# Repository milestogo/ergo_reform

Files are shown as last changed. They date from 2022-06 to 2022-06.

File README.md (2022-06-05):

# ergo_reform
ergonomic keyboard remix for the  MNT Reform laptop

This keyboard design is for educational purposes: for me to learn through experimenting, or for for you to educate me. Little remains of MNT's tested design. I have not tested the current version.  Hardware may have dangerous, ignorant or time wasting mistakes. Software is not guaranteed to run or be useful for any purpose. 

## Images
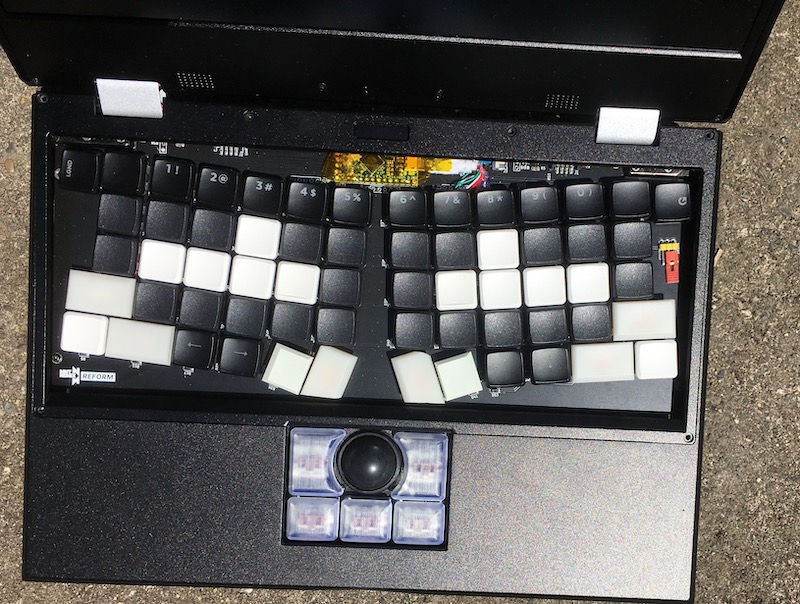
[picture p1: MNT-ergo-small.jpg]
Ergo keyboard V1


## Changes from MNT reform

* Ergonomic key layout.
* Removed backlight
* Added optional Kailh sockets for switches without RGB backlight. These sockets are cheaper than switches, so I like them in protototypes. While there is room for the sockets above the motherboard, it's only a couple thicknesses of paper. This probably reduces cooling and may permit chort circuits. 
* Removed surface mount Atmega32u4 (cost and chip shortages). Instead it uses the 3 volt Adafruit itsy bitsy. https://learn.adafruit.com/introducting-itsy-bitsy-32u4/pinouts you must hack a USB cable to connect the MCU to the keyboard (see screenprint for "airwire"). You MUST modify the itsyBitsy to disable or remove the 3v3 regulator. Failure to do so may damage the motherboard. 
* Optional power off switch/jumper that can completly remove power to the keyboard.
* Lots of break out pins, so that it should be possible to use the PCB with other MCUs.
* Desktop option for through hole OLED modules. Available from online retailers
* Added partial RGB backlighting. Keys ESC,~,1,2, F, Thumb keys, J, 9,0,-,= have backlights. This is enough to show battery voltage or where to put your hand in the dark. There are jumpers to bypass the top row LEDs, or add separate LED strips. This uses SK Mini-E rgb lights. 

## errata / changelog / todo
* V0 - the pictured version - had the power disconnect on the 5 volt side instead of 3v. ooops. 

# License
This work is derived from work Copyright 2018-2020 MNT Research GmbH.
Modifications Copyright 2022 milestogo are released under the license matching the MNT reform original file or the attached MIT license where not othewise specified.  

The following licenses are used in the project, unless specified differently in a particular subfolder:

- Schematics, PCBs: [CERN-OHL-S v2](https://www.ohwr.org/project/cernohl/wikis/uploads/002d0b7d5066e6b3829168730237bddb/cern_ohl_s_v2.txt)
- Other documentation, artwork, photos and drawings that are not trademarks (see below): [CC-BY-SA 4.0](https://creativecommons.org/licenses/by-sa/4.0/legalcode)
- Software, firmware: Various. [GPL 3.0](https://www.gnu.org/licenses/gpl-3.0.en.html) if not specified otherwise in the file/subdirectory.

The "MNT" and "MNT REFORM" logos are trademarks of MNT Research GmbH. 

## MIT license
Permission is hereby granted, free of charge, to any person obtaining a copy of this software and associated documentation files (the “Software”), to deal in the Software without restriction, including without limitation the rights to use, copy, modify, merge, publish, distribute, sublicense, and/or sell copies of the Software, and to permit persons to whom the Software is furnished to do so, subject to the following conditions:

The above copyright notice and this permission notice shall be included in all copies or substantial portions of the Software.

THE SOFTWARE IS PROVIDED “AS IS”, WITHOUT WARRANTY OF ANY KIND, EXPRESS OR IMPLIED, INCLUDING BUT NOT LIMITED TO THE WARRANTIES OF MERCHANTABILITY, FITNESS FOR A PARTICULAR PURPOSE AND NONINFRINGEMENT. IN NO EVENT SHALL THE AUTHORS OR COPYRIGHT HOLDERS BE LIABLE FOR ANY CLAIM, DAMAGES OR OTHER LIABILITY, WHETHER IN AN ACTION OF CONTRACT, TORT OR OTHERWISE, ARISING FROM, OUT OF OR IN CONNECTION WITH THE SOFTWARE OR THE USE OR OTHER DEALINGS IN THE SOFTWARE.

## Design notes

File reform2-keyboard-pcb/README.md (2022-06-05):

# keyboard remix by milestogo

This keyboard design is for educational purposes: for me to learn through experimenting, or for for you to educate me. 
Little remains of MNT's tested design. I have not tested. It may have dangerous or time-wasting errors. 

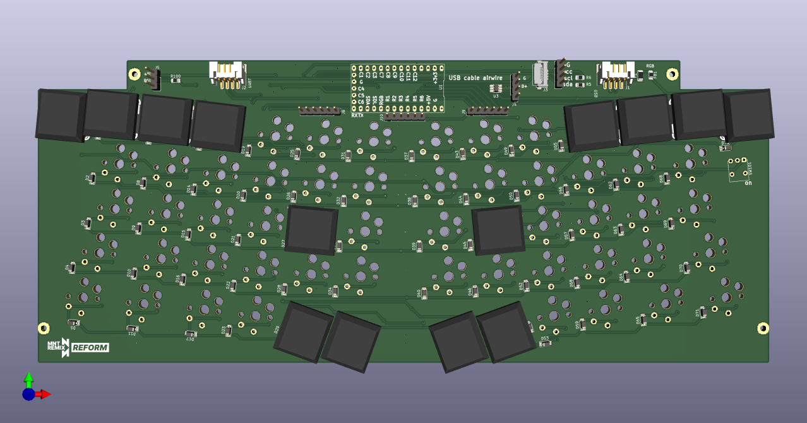
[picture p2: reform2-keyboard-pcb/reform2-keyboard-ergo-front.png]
Front of PCB image Front of PCB


Warning!
this PCB is designed to use an adafruit itsy bitsy 3v3 model. You MUST disable the 3v regulator if you want to avoid doing bad things to your mnt reform laptop. Remove R9 above the voltage regulator at a minimum. Remove voltage regulator to be sure. 
Remember to flash the MCU before removing the regulator. Place a current limiting resistor at J14, marked "EN" to temporarily enable the regulator. 

Changes from MNT reform
- Ergonomic key layout. 
- Removed backlight
- Added partial RGB backlighting. Keys ESC,~,1,2, F, Thumb keys, J, 9,0,-,= have backlights. This is enough to show battery voltage or where to put your hand in the dark. There are jumpers to bypass the top row LEDs, or add separate LED strips. This uses SK Mini-E rgb lights. Since they are bottom mount and optional, the power caps for them are also bottom & optional. 
- Added optional Kailh sockets for switches without RGB backlight. These sockets are cheaper than switches, so I like them in protototypes. These reduce thermal and short protection. 
- Removed surface mount Atmega32u4 and related voltage chips (cost and chip shortages). Instead it uses the 3 volt Adafruit itsy bitsy. https://learn.adafruit.com/introducting-itsy-bitsy-32u4/pinouts
--you must hack a USB cable to connect the MCU  to the keyboard (see silkscreen for "USB airwire"). 
- Optional power off switch/jumper that can completely remove 3v3 power to the keyboard.
- Lots of break out pins, so that it should be possible to use the PCB with other MCUs.  
- Desktop option for through hole OLED modules. Available from online retailers

These changes are made available under the MIT License: 
Copyright © 2022 milestogo

Permission is hereby granted, free of charge, to any person obtaining a copy of this software and associated documentation files (the “Software”), to deal in the Software without restriction, including without limitation the rights to use, copy, modify, merge, publish, distribute, sublicense, and/or sell copies of the Software, and to permit persons to whom the Software is furnished to do so, subject to the following conditions:

The above copyright notice and this permission notice shall be included in all copies or substantial portions of the Software.

THE SOFTWARE IS PROVIDED “AS IS”, WITHOUT WARRANTY OF ANY KIND, EXPRESS OR IMPLIED, INCLUDING BUT NOT LIMITED TO THE WARRANTIES OF MERCHANTABILITY, FITNESS FOR A PARTICULAR PURPOSE AND NONINFRINGEMENT. IN NO EVENT SHALL THE AUTHORS OR COPYRIGHT HOLDERS BE LIABLE FOR ANY CLAIM, DAMAGES OR OTHER LIABILITY, WHETHER IN AN ACTION OF CONTRACT, TORT OR OTHERWISE, ARISING FROM, OUT OF OR IN CONNECTION WITH THE SOFTWARE OR THE USE OR OTHER DEALINGS IN THE SOFTWARE.

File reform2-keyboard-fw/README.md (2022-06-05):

# MNT Reform 2.0 Keyboard Firmware

## Code Structure

- `constants.h`: Define which keyboard variant you want to build for
- `keyboard.c`: Main entrypoint that includes the chosen matrix file (keyboard layout)
- `matrix.h`: Keyboard layout definition (default)
- `matrix_*.h`: Alternative layouts
- `backlight.c`: Keyboard backlight control
- `menu.c`: OLED Menu handling
- `oled.c`: OLED graphics control
- `remote.c`: Communication with MNT Reform motherboard LPC
- `hid_report.c`: USB HID raw report handler (commands sent by OS)
- `powersave.c`: Low power/sleep mode
- `descriptors.c`: USB HID descriptors
- `i2c.c`: Soft I2C master implementation (for OLED)
- `serial.c`: Soft UART implementation
- `font.c`: Bitmap data for OLED font and icons

## Dependencies

### Debian/Ubuntu

`apt install gcc-avr avr-libc dfu-programmer`

### Mac

*TODO: is this correct?*

```
brew tap osx-cross/avr
brew install avr-gcc
brew install dfu-programmer
```

## Hacking

To change the keyboard layout, adjust the `matrix` arrays in `keyboard.c`.

## Building

*Important*: Adjust the variant settings in `constants.h` do match your keyboard or laptop model.
I.e., if you are targeting the Standalone Keyboard, uncomment the `#define KBD_VARIANT_STANDALONE`.

To build, type:
`make`

To flash, put your keyboard into [flashing mode](https://mntre.com/reform2/handbook/parts.html#keyboard-firmware) and run:
`sudo ./flash.sh`

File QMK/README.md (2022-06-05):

#Incomplete work

This firwmare does not yet work in the mnt reform.
The keymap and OLED graphics should work. 
The serial connection has not been tested. 
The problem is that QMK expects USB power at boot. Looking at similar examples in keyboards/bioi/main.c , we probably need to create a custom main.c
The order would be 
1) init everything. 
2) open serial, find the LPC. 
3) Wait for power on, talk to LPC, exit power saving. 
4) Wait for USB VBUS
5) Start USB, 
6) standard QMK boot cycle. 

To use, copy or symlink this directory into the $QMK/keyboards/ directory

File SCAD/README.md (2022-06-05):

# Lorize: a family of low profile 60% ergonomic keyboards that aren't too weird.  

These should be familiar to users of a MS natural or Sculpt keyboard, but pull in elements from the boardrun, alice, and kinesis keyboards. 
Available in desktop and MNT reform versions.

The lorize.scad file is intended to be used with the openscad configurator. You can change the type of keyboard (desktop, laptop, mutants), and the layer. The output can be used for laser cutting plate and case files. The POS files are used as an easy way to export centroid information from kicad & import into SCAD, which is used to make the bottom layer cutouts. 

lorize3 folder is for a desktop version of the PCB. it can be split for tenting, or used unsplit. This PCB can be soldered using only through hole 
techniques (no stencil).

The PCB for the laptop version is located at github milestogo/reform,in the ergo1 branch. This was done as a remix of the original keyboard, so that the factory firmware will still work. The board was updated to be single sided to reduce cost/effort of assembly. There isn't quite enough room to fit on top to fit a pro micro, so it requires SMD work. 

#Todos.
the latest ergo reform PCB thumb positions are a few mm away from the scad positions. Update.

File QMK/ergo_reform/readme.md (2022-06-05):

# ergo_reform

ergo_reform

*A short description of the keyboard/project*

* Keyboard Maintainer: [milestogo](https://github.com/milestogo)
* Hardware Supported: *The PCBs, controllers supported*
* Hardware Availability: *Links to where you can find this hardware*

Make example for this keyboard (after setting up your build environment):

    make ergo_reform:default

Flashing example for this keyboard:

    make ergo_reform:default:flash

See the [build environment setup](https://docs.qmk.fm/#/getting_started_build_tools) and the [make instructions](https://docs.qmk.fm/#/getting_started_make_guide) for more information. Brand new to QMK? Start with our [Complete Newbs Guide](https://docs.qmk.fm/#/newbs).

## Bootloader

Enter the bootloader in 3 ways:

* **Bootmagic reset**: Hold down the key at (0,0) in the matrix (usually the top left key or Escape) and plug in the keyboard
* **Physical reset button**: Briefly press the button on the back of the PCB - some may have pads you must short instead
* **Keycode in layout**: Press the key mapped to `RESET` if it is available

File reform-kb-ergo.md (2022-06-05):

## Design goals & trade-offs:

# Make it hurt less
Remove as many of the un-ergonomic factors as possible, while remaining within the footprint of the Reform keyboard.

# Optimize for portable use on the lap.
People will put their laptops at different heights and rotations. Most of these won't be ergonomic. We'll try to avoid anything that makes it worse.

While we can increase the hand to hand spacing up to almost 4cm, this moves the palm resting position out to the side enough that it unbalances a laptop when only one hand is used. Instead we're increasing the angle & keeping the hands relatively close. This normally requires an increase in tenting angle, which we're appoximating by changing the pinky location. 

Most designs here separate the D ahd K middle fingers by ~106mm. Most ergo keyboards are 2-3 cm further apart, but tip the laptop.  From a trawl through anthropometric data, people with forearms of average North American size should have a ~18 degree angle, but we're limited to  ~14 degrees in order to stay within the limits of the reform keyboard Y depth. Too flat is probably less bad than too angled given the range of positions a laptop will be placed in. 

best angle = atan((shoulders width -d_to_k_key_spacing)/( 2 * armlen));

#Minimize learning curve
  * Removing the number row is a big step for most people.  Providing a comfortable 10key layer will help some people, this is down to the key map. 
  * Removing the Fkeys is bad for some, but is easier to solve with a FN key/keymap. 
  * Use big keys where people are used to big keys. Most designs use 1.5U keys for shift & GUI, to accomodate current muscle memory.  
  
# Avoid custom keycaps
* We want to only use 1u and 1.5u keycaps. In practice, the top right and top left key may need to be shaved down to clear the MNNT bezel. The thumb buttons would benefit from a more diagonal shape. 

# Reduce ulnar flexion/deviation
Ulnar flexion occurs when the fingers are not in line with the bones of the forearm, so that there is a <180 degree angle between little finger and the outside of the arm). 

Ulnar flexion is the norm on laptop keyboards, where the hands are too close together and the keyboard is entirely parallel to the chest.

To fix this, we want the front to back line of keys to be  parallel to the bones of the forearm. This is changes depending on how far apart the hands are (x axis) as this changes the angle between the forearms and the chest.  Reducing pronation of the hands (thumbs to ceiling) allows the fingers to move together. Staggering keys so that the little finger is further away and the index finger is closer has the effect of rotating the center of the palm around the z-axis, reducing ulnar flexion. This technique has a limited range, beause people have different size fingers. 

Because of the limited depth of the reform keyboard, we can't use much finger stagger, but we've added some.  

# Minimize Radial Deviation
Radial flexion is caused by roating the hand inwards, as in rotating the palm to allow the little finger to hit the backspace key,  or to hit a key inwards of the index finger.  Laptop keyboards start with so much ulnar deviation, radial movement usually isn't a problem. Some variations here (smallreform_thumbs) add a column of keys between the index fingers. The lower positions are not good for radial deviation when activated by the fingers, and create ulnar deviation when activated by the thumb. Save them for unused keys.

#Reduce pronation of the hand
Pronation is palms forced parallel to the floor, when they would be more comfortable with the thumbs pointing upwards.

We gain a litle bit here by straightening the ulnar deviation, but proper tenting would require changing the top face of the laptop.

# Move work from the little finger to the Thumbs.
 This helps avoid "emacs-pinky", and somewhat reduces the need to pronate the hand in chorded combinations. Frequently used keys like Backspace, GUI, CTL and Enter should be moved to thumb keys.

 Some people have flexible or long thumbs that allow them to hit keys underneath the index fingers. Most people use excessive wrist flexion to force it.  

 There are two thumb keys on each hand in all designs. In the smallreform_thumbs version has 5 in total, with slightly worse ergonomics. While the bottom index finger key could be used for an inner thumb key, but I suspect it is bad for most people. 

# Avoid Wrist extension
Where the tip of the fingers are above the line from elbow to wrist. Laptops create a problem when the user is pressing down on the palms to keep the laptop steady.  Possibly some thin (~3-5mm), cork or rubber  wrist wrests could help wrist extension & contribute a degree or two of tenting?

# Think about palmar flexion
Where the tip of the fingers are below the line from the elbow to the wrists. Also known as the T-rex or bunny position. This can be a problem for tall laptops on tables, where there isn't a good line from the elbows to the keys. Ideally we'd move the laptop to the lap or use a separate keyboard.

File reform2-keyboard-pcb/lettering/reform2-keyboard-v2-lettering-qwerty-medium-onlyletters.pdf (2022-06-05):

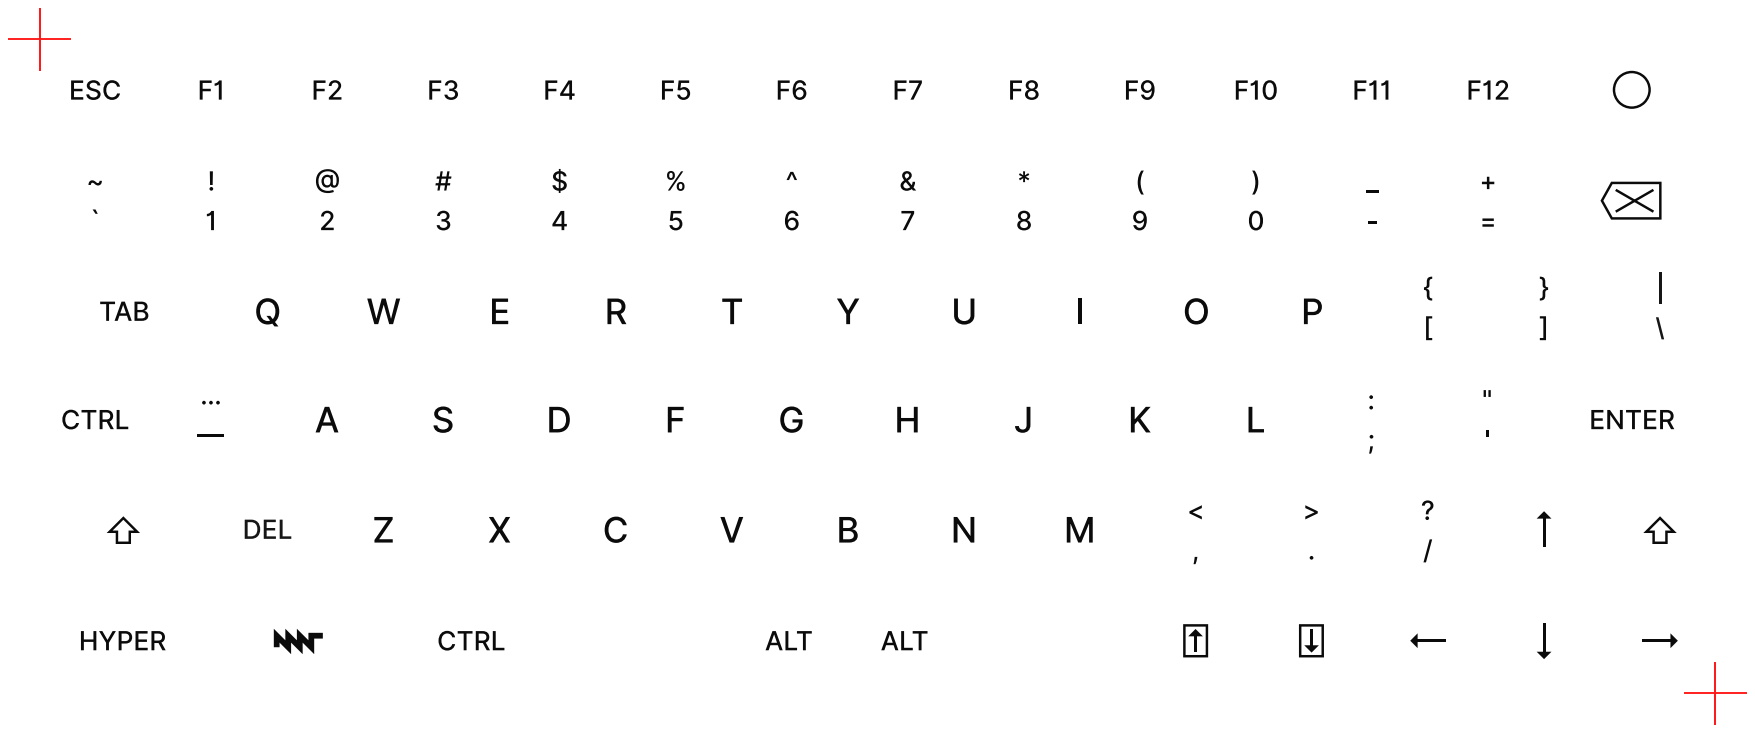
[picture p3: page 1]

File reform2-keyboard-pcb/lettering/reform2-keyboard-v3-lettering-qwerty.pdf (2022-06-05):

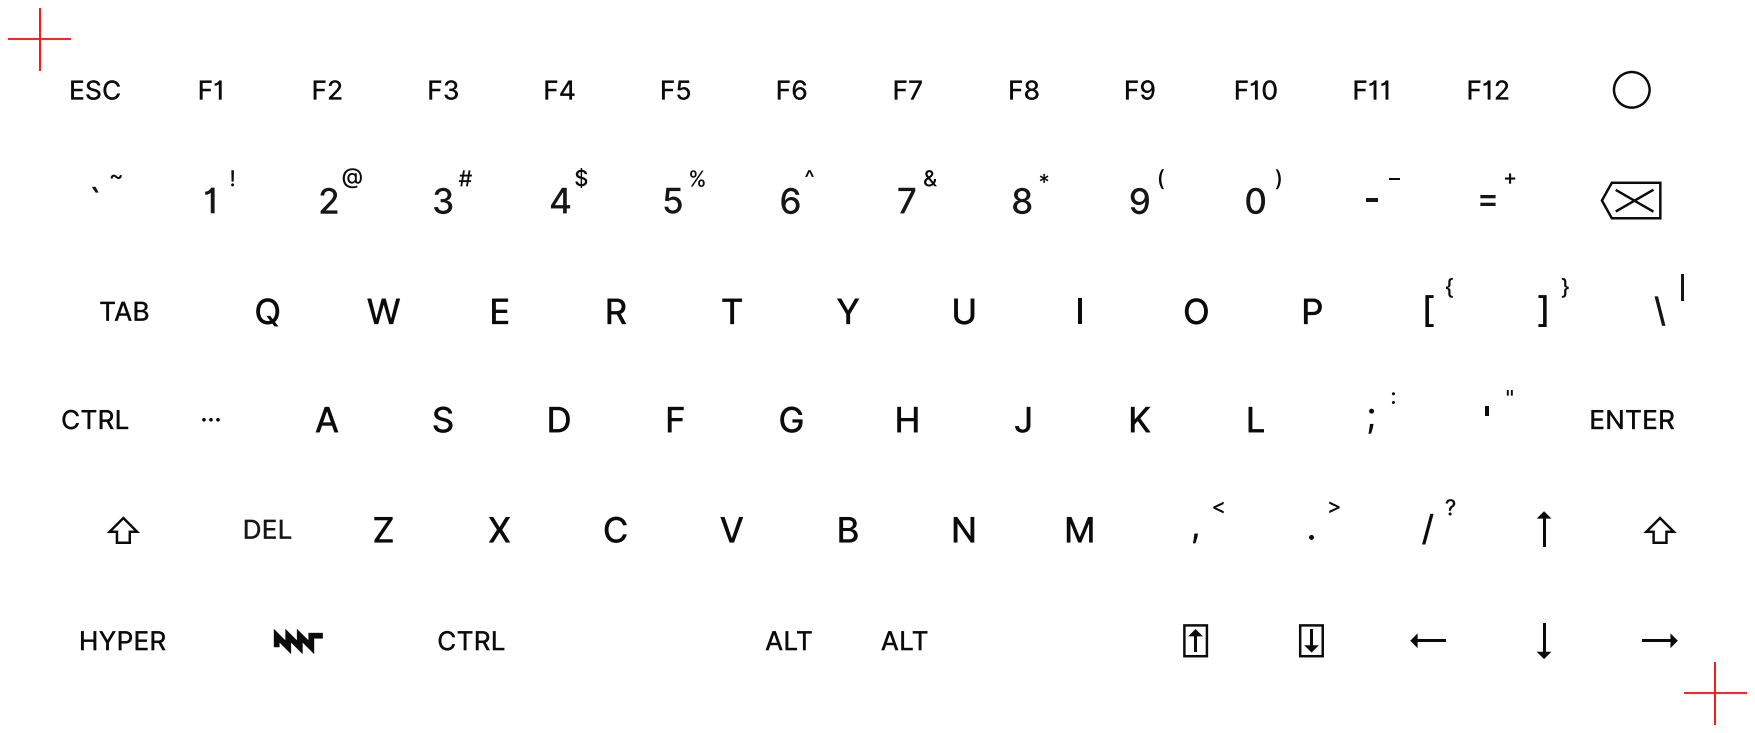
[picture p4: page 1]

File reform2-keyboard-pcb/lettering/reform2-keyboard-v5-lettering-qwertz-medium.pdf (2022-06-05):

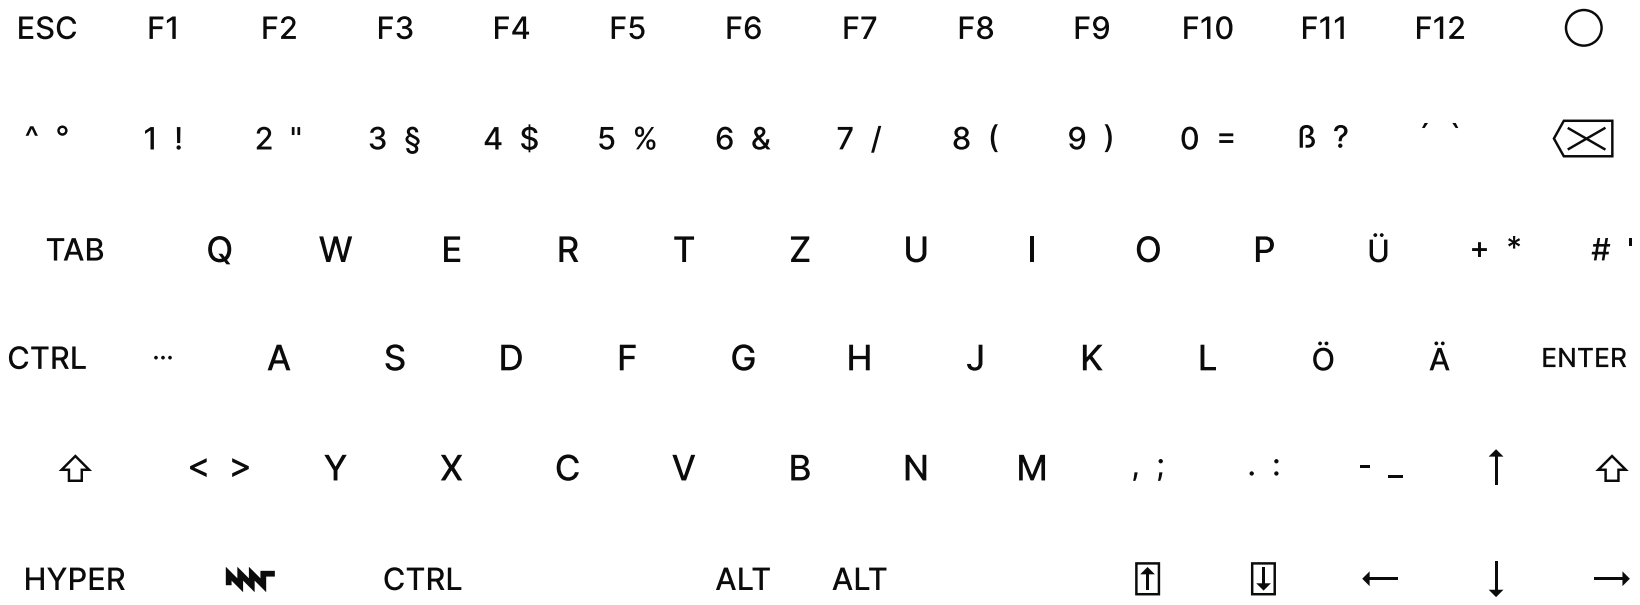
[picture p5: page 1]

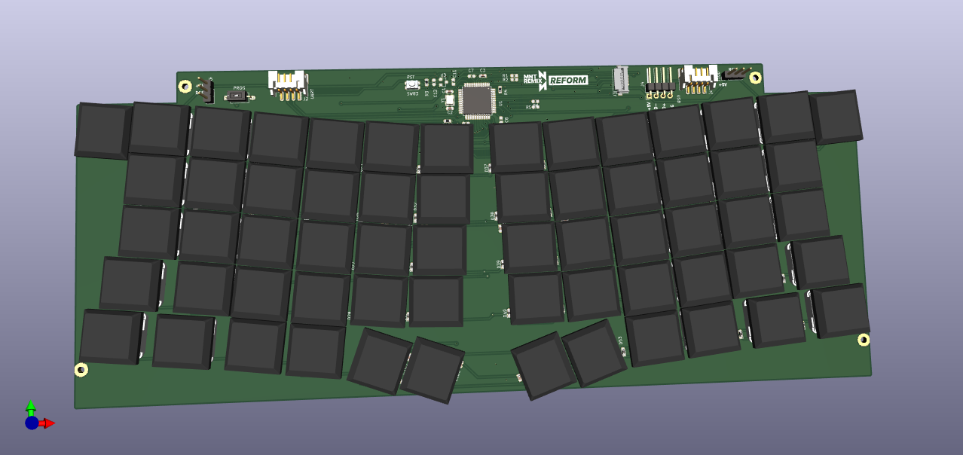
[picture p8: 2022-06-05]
reform2-keyboard-pcb/reform2-keyboard-ergo.png

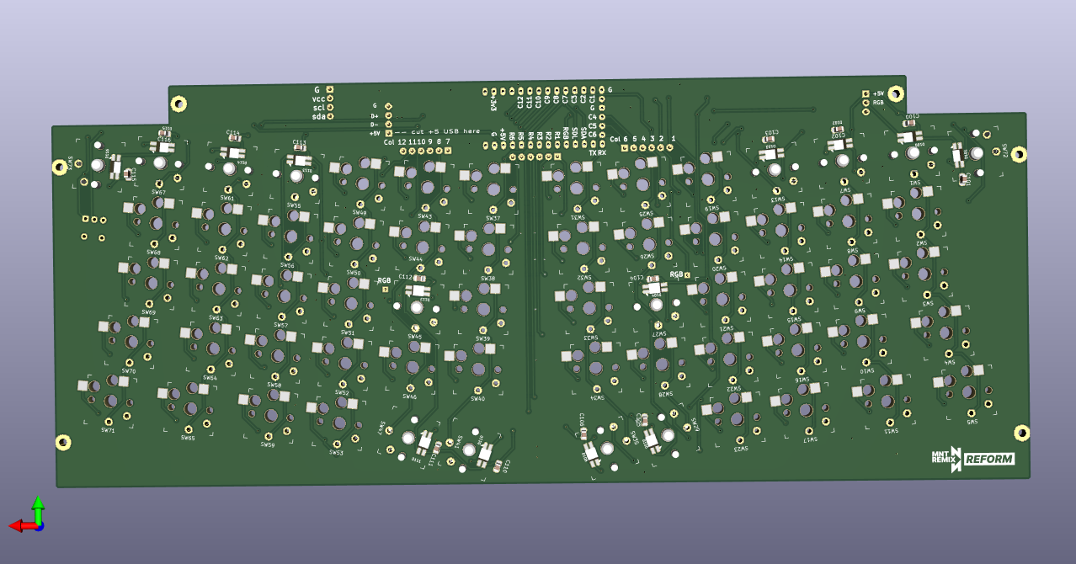
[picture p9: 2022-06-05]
reform2-keyboard-pcb/reform2-keyboard-ergo-back.png

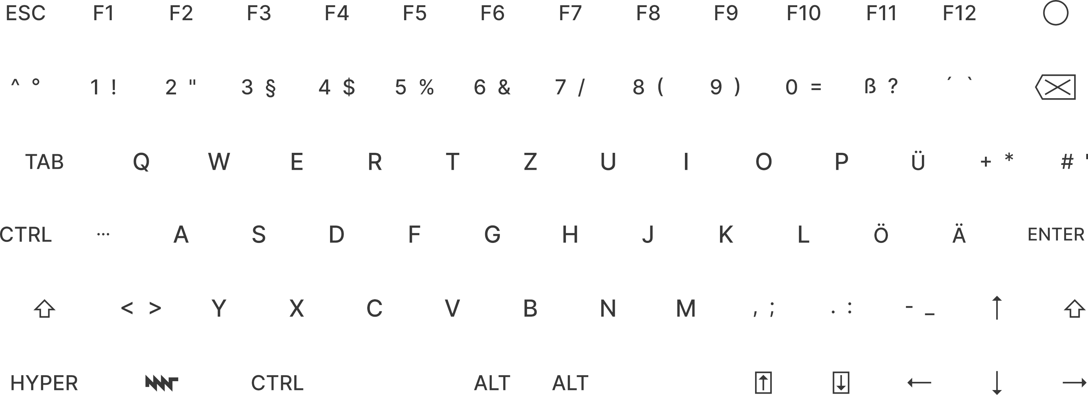
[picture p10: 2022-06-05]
reform2-keyboard-pcb/lettering/reform2-keyboard-v5-lettering-qwertz-medium.png

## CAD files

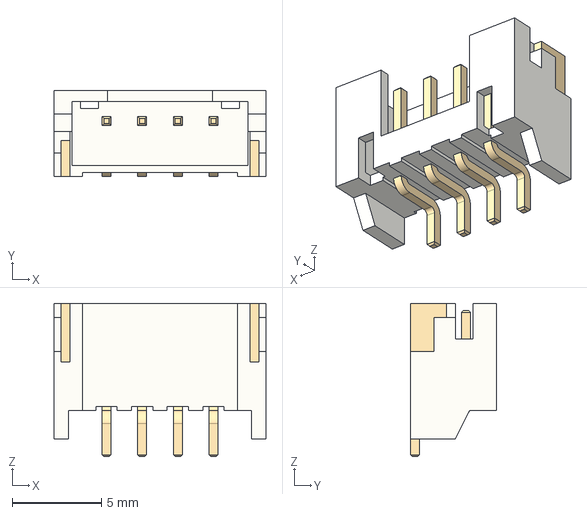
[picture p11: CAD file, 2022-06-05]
reform2-keyboard-pcb/3d-models/S4B-PH-SM4-TB.stp
11.9 x 4.80 x 8.60 mm

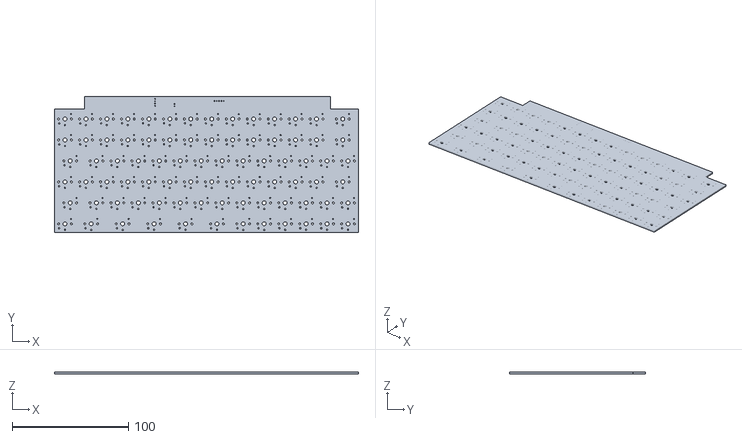
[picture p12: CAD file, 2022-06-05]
reform2-keyboard-pcb/reform2-kbdtest.stl
261.0 x 116.8 x 1.60

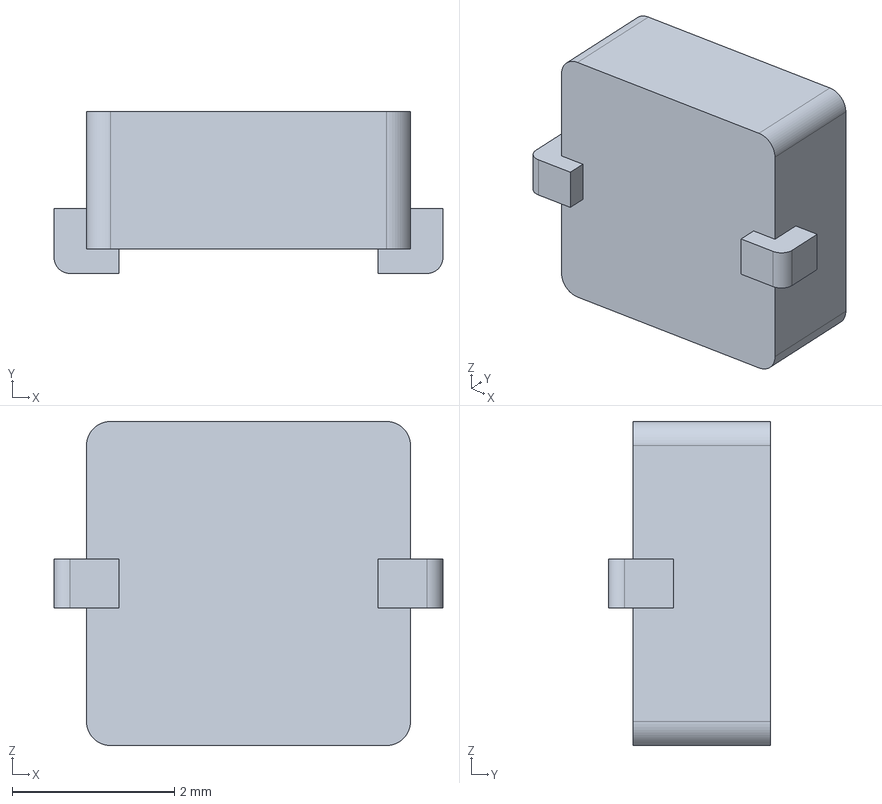
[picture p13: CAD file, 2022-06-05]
reform2-keyboard-pcb/3d-models/srp4020.stp
4.80 x 2.00 x 4.00 mm

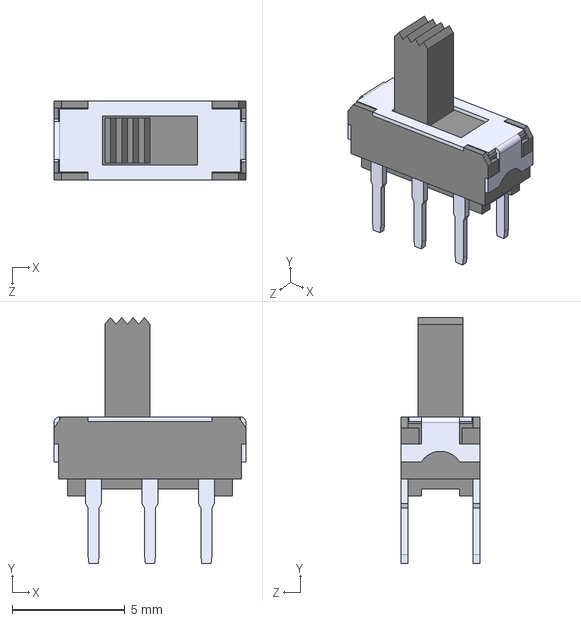
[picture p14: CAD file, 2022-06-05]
reform2-keyboard-pcb/3d-models/EG1271A.step
8.50 x 10.9 x 3.50 mm

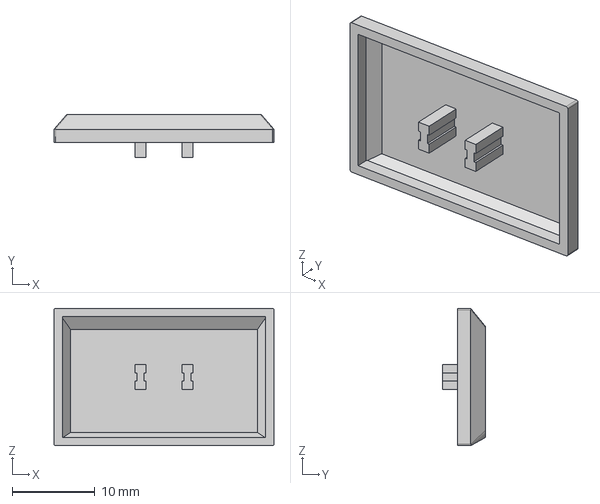
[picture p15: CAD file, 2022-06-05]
reform2-keyboard-pcb/3d-models/Kailh - keycap 1.5 v2.step
26.6 x 5.23 x 16.6 mm

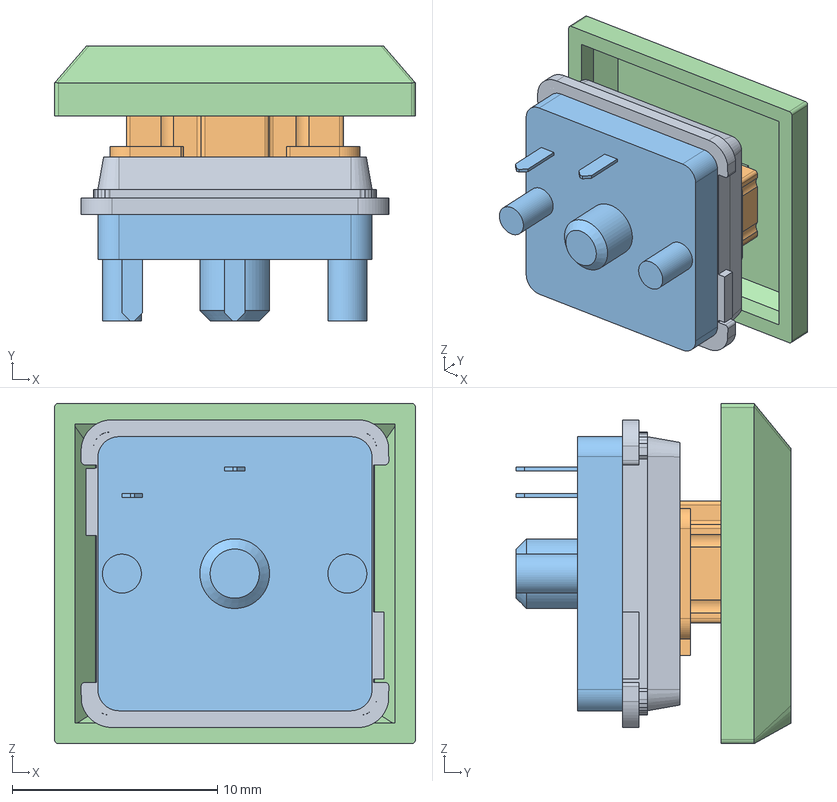
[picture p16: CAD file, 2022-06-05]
reform2-keyboard-pcb/3d-models/Kailh_keycap-switch_system_1x1.step
17.6 x 13.4 x 16.6 mm
CPG135001D02 BROWN
Kailh_keycap

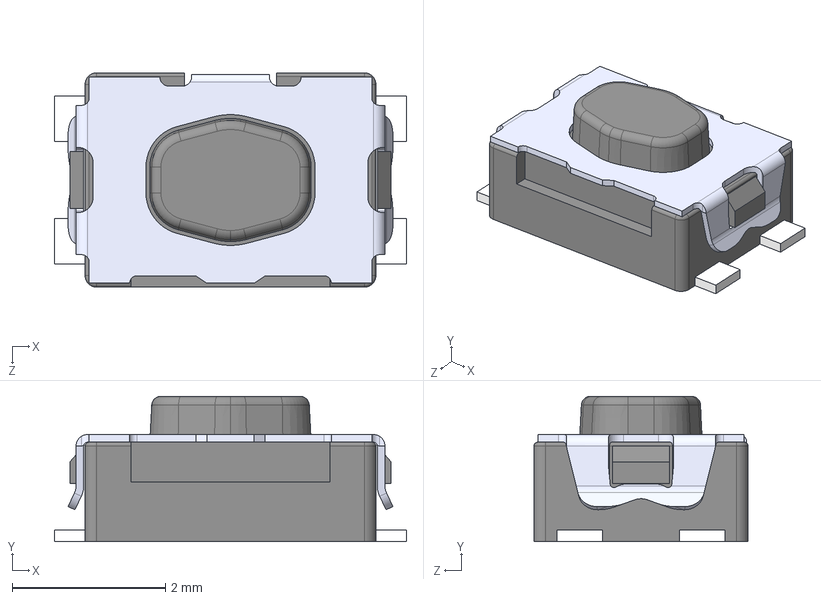
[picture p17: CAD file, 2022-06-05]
reform2-keyboard-pcb/3d-models/KMR221GLFS.step
4.60 x 1.90 x 2.80 mm

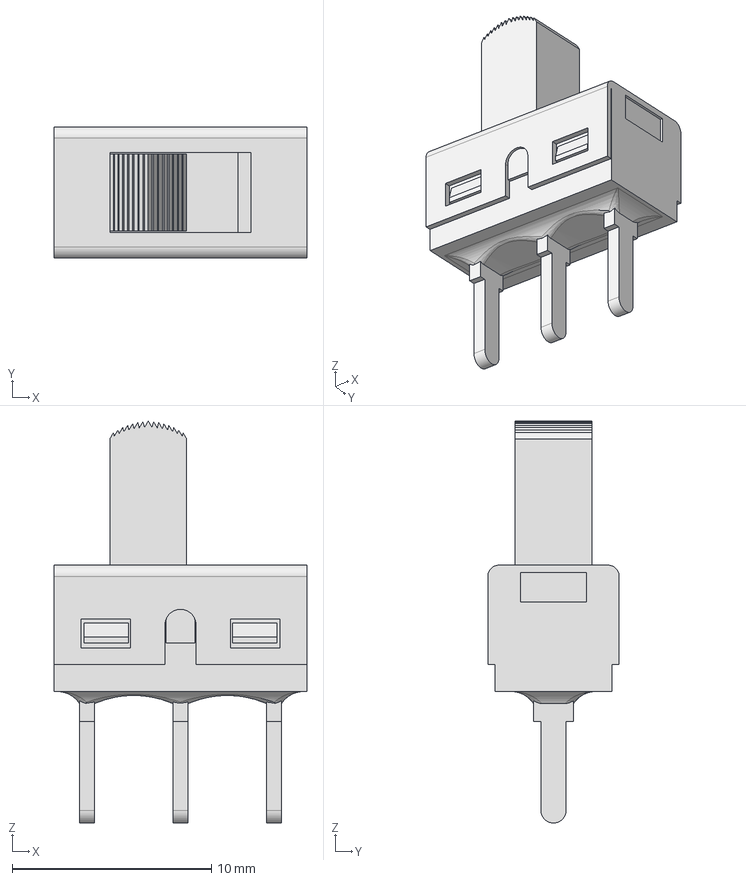
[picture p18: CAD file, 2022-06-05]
reform2-keyboard-pcb/3d-models/500SSPxS2M2xEA.stp
12.7 x 6.60 x 20.2 mm

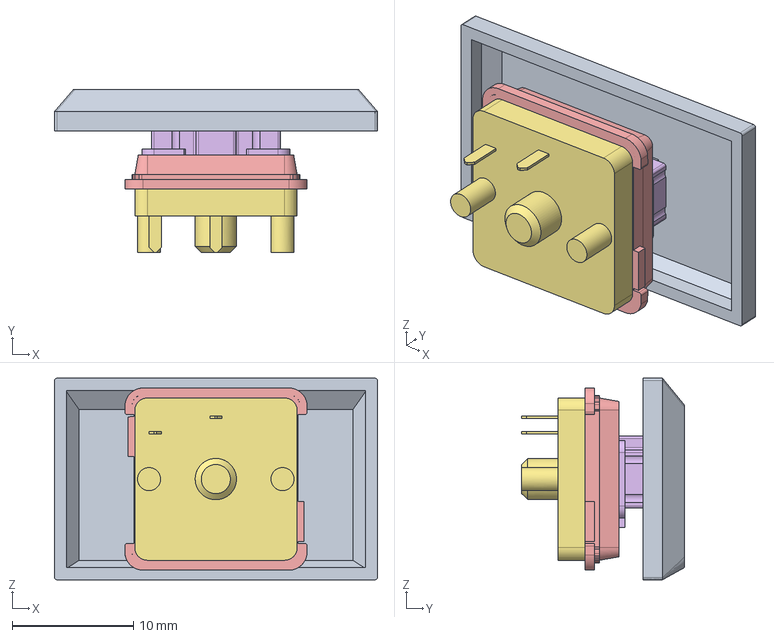
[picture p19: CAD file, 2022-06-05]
reform2-keyboard-pcb/3d-models/Kailh_keycap-switch_system_1.5x1.step
26.6 x 13.4 x 16.6 mm

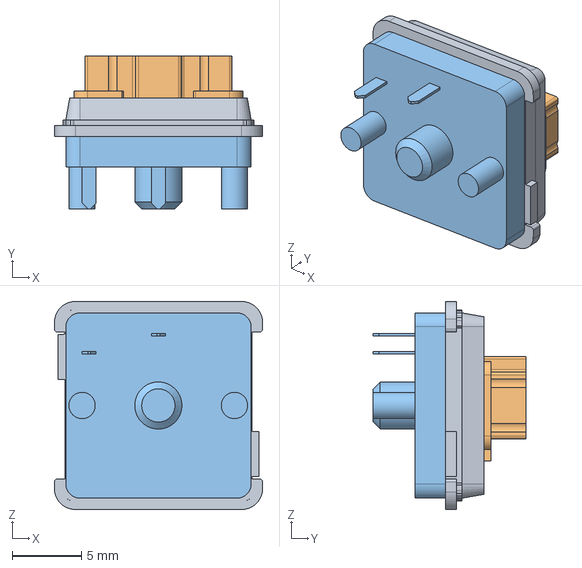
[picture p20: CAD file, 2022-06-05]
reform2-keyboard-pcb/3d-models/CPG135001D02 BROWN v5.step
15.0 x 11.0 x 15.0 mm

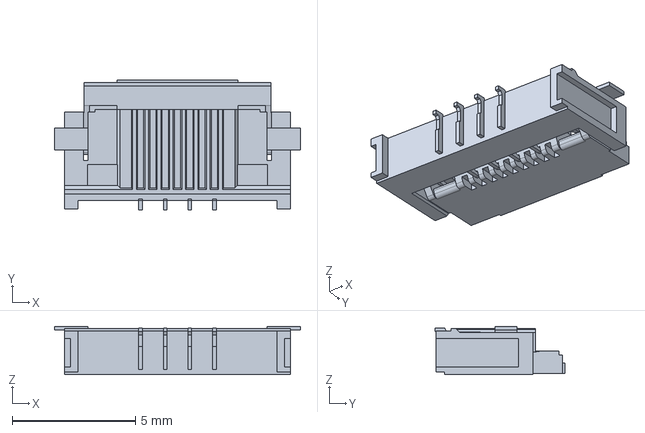
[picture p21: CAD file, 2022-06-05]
reform2-keyboard-pcb/3d-models/2005280040.stp
10.0 x 5.30 x 1.96 mm

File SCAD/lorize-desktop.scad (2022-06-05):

/* Desktop specific configs for lorize keyboard */



// desktop shape functions.

module walkpoints(radius, start, count, nodes) {
  for (c = [start:count]) {
    translate(nodes[c]) circle(r = radius);
  }
}

RightCorners = [
  [ 0, 0 ],
  [ 0, 58 ],     // center top
  [ 62, 64 ],    //  outsidetop of mcu holder 192,36
  [ 72, 48 ],    // near u key // 205,49.5
  [ 112.5, 49 ], // upper right
  [ 125, 3 ],    // bump on side
  [ 129, -35 ],  // bottom right
  [ 27, -53 ],   // side of spacebar
  [ 0, -53 ],    // bottom center
  [ 0, 0 ],
];

/*raw, center at x=130,y=100
130,42
130,100
130, 153
200,49
60,49
254,98
6,98
148,135
112,135
*/

MountingHoles = [
  [ 0, 58 ],
  [ 0, 0 ],
  [ 0, -53 ],
  [ 70, 51 ],
  [ -70, 51 ],
  [ -124, 2 ],
  [ 124, 2 ],
  [ 18, -36 ],
  [ -18, -35 ],
];

front = 140;
gap = -20;
PalmrestMid = [
  // middle ones, no gap added to allow access to keys
  [ 142, 10 - front ],
  [ 129, -35 ], // bottom right
  [ 27, -53 ],  // side of spacebar
  [ 0, -53 ],   // bottom center
  [ 40, 5 - front ],
  [ 00, 5 - front ],
];

PalmrestTop = [
  // middle ones, no gap added to allow access to keys
  [ 142, 10 - front ],
  [ 129, -35 ], // bottom right
  [ 40, -53 ],  // side of spacebar
  [ 70, -53 ],  // bottom center
  [ 50, 5 - front ],

];

LowerPalmrestCorners = [
  [ 145, 10 - front ],
  [ 129, -35 ], // bottom right
  [ 27, -53 ],  // side of spacebar
  [ 0, -53 ],   // bottom center
  [ 50, -front ],
  [ 0, -front ],

];

module hullpalms_mid() { // upper palms
                         // no fancy angles, so we can do both sides.
  difference() {
    union() {
      hull() walkpoints(5, 0, 5, PalmrestMid);

      mirror([ 1, 0, 0 ]) hull() walkpoints(5, 0, 5, PalmrestMid);
    }

    scale(1.01) hullaplate();

    // centering holes for palmrest.
    for (x = [ 100, 80, -80, -100 ])
      translate([ x, -100, 0 ]) circle(r = 3 / 2);
  }
}

module hullpalms_top() { // upper palms
                         // no fancy angles, so we can do both sides.
  difference() {
    union() {
      hull() walkpoints(5, 0, 4, PalmrestTop);

      *mirror([ 1, 0, 0 ]) hull() walkpoints(5, 0, 5, PalmrestTop);
    }

    translate([ 0, -18, 0 ]) scale(1.05) hullaplate(0);

    translate([ 0, -150 ]) rotate(45) square([ 150, 150 ]);

    // centering holes for palmrest.
    for (x = [ 100, 80 ])
      translate([ x, -100, 0 ]) circle(r = 3 / 2);
  }
}

module hullpalms() {
  // no fancy angles, so we can do both sides.
  difference() {
    union() {
      hull() walkpoints(5, 0, 5, LowerPalmrestCorners);

      mirror([ 1, 0, 0 ]) hull() walkpoints(5, 0, 5, LowerPalmrestCorners);
    }
    // always cut out mounting holes
    for (c = [0:8]) {
      translate(MountingHoles[c]) circle(r = m3);
    }

    // centering holes for palmrest.
    for (x = [ 100, 80, -80, -100 ])
      translate([ x, -100, 0 ]) circle(r = 3 / 2);
  }
}

module hullaplate(doholes) {
  difference() {
    union() { // need to do two different hull points.
      hull() walkpoints(5, 0, 3, RightCorners);
      hull() walkpoints(5, 3, 9, RightCorners);

      mirror([ 1, 0, 0 ]) {
        hull() walkpoints(5, 0, 3, RightCorners);
        hull() walkpoints(5, 3, 9, RightCorners);
      }
    }

    if (doholes) {
      // always cut out mounting holes
      for (c = [0:8]) {
        translate(MountingHoles[c]) circle(r = m3);
      }
    }
  }
}

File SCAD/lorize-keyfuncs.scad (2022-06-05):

// Lorize-keyfuncs.scad
// All of the switch & MCU descriptions & wrapper functions. 


module dokey() {
  /* how big is a 1u choc cap?
  generic black keycap set, x=17.6 y=16.65
  PLUM keyboard 18x18
  per key white 17.6x16.65
  transparent 17.45 x 17.82
  mbk 17,48 x 16.43
  */

  if (0 == layer) { // debug caps
    difference() {
      square([ 17.7, 16.7 ], center = true);
      circle(r = 3);
    }
  } else if (1 == layer) { // switch plate
    square([ 14, 14 ], center = true);

  } else { // PCB - replace with choc pcb footprint some day - useful for kicad
           // conversion later?
    do_choc_under();
  }
}

module dolongkey() {
  /* how big is a 1.5u?

  generic nylon 26.6x16.6
  generic white 26.7x16.65
  generic black 26.55x16.5
  mbk 26.6 x 16.5

  */
  if (0 == layer) {
    difference() {
      square([ 26.75, 17 ], center = true);
      circle(r = 3);
    }
  } else if (1 == layer) {
    square([ 14, 14 ], center = true);

  } else { // PCB
    do_choc_under();
  }
}



//// DebugKey
/// Wrapper for keys that outputs X,Y, rotation, so that it is easy to import to kicad. 
/// 
/// Inputs x_origin,y_origin, angle of orgin from horizontal, x increment ,y increment,
/// additional angle of column, separation between hands, do_longkey,
/// per_key_rotation, mirror key, col,row


module debugkey(x_o, y_o, a_o, x, y, a_col, separation, long, a_key,
                is_mirror,col,row) {

  // even if we are mirroring motions, don't want to mirror parts. So mirror
  // them again.

  translate([ separation, 0, 0 ]) {
    rotate(a_o) translate([ x_o, y_o, 0 ])
       rotate(a_col) translate([ x, y, 0 ])

        if (long) {
      if (a_key) {
        rotate(a_key) if (is_mirror) { mirror([ 1, 0, 0 ]) dolongkey(); }
        else {
          dolongkey();
        }
      } else {
        if (is_mirror) {
          mirror([ 1, 0, 0 ]) dolongkey();
        } else {
          dolongkey();
        }
      }
    }
    else {
      if (a_key) {
        rotate(a_key) if (is_mirror) { mirror([ 1, 0, 0 ]) dokey(); }
        else {
          dokey();
        }
      } else {
        if (is_mirror) {
          mirror([ 1, 0, 0 ]) dokey();
        } else {
          dokey();
        }
      }
    }
  }

  innerx = (x * cos(a_col) - y * sin(a_col));
  innery = (x * sin(a_col) + y * cos(a_col));

  outangle = a_key + a_col + a_o;
  out_x = separation + ((x_o + innerx) * cos(a_o) - (y_o + innery) * sin(a_o));
  out_y = ((x_o + innerx) * sin(a_o) + (y_o + innery) * cos(a_o));

  if (0 == layer) { // debug caps
    color("blue") translate([ out_x, out_y, 0 ]) rotate(outangle) circle(4 / 2);
  }

// export offsets from center of PCB/DXF. 
 pcbX=276.9/2 +5; // 130 for desktop
 pcbY=30.74+(134-30.74)/2; //100 for desktop 

// Switch diode near lower left of switch
diodeX=-14/2-3 ;// offset for diode
diodeY=-1.5+14/2;

  // SMD led near center of switch hole. This may need adjustment due to stairsteps + rottion
ledX=-0.036;
ledY= -4.762;



 // KiCad's Y axis is opposite Scads, so flip
  if (is_mirror == 0)  { // right side

    //switch_kicad = str ( "(at ",pcbX+out_x, " " ,pcbY-out_y, " " ,outangle, ")" );
    //diode_kicad =  str ( "(at ",pcbX+out_x + diodeX, " " ,pcbY-out_y + diodeY, " " ,90+outangle, ")" );
    //led_kicad =  str ( "(at ",pcbX+out_x + ledX, " " ,pcbY-out_y + ledY, " " ,outangle, ")" );
    
    DiS = str ("D" ,  switch_layout[row+centerrow][col+7]);
    LeS = str ("D" ,  led_layout[row+centerrow][col+7]);
    SwS= str ("SW" ,  switch_layout[row+centerrow][col+7]);

    // Evil horrible BUG TODO, not doing proper trig based on angle of switch, manually kludging diode  right 2 mm
    kludge= 1.5;
    echo("R",col+7, row+centerrow, SwS,pcbX+out_x,pcbY-out_y,outangle, DiS, pcbX+out_x + diodeX +kludge,pcbY-out_y + diodeY, 90+outangle, LeS, pcbX+out_x + ledX,pcbY-out_y + ledY, outangle );
  } else {
     /// left side   
      SwS= str ("SW" ,  switch_layout[row+centerrow][6-col]);
      DiS = str ("D" ,  switch_layout[row+centerrow][6-col]);
      LeS = str ("D" ,  led_layout[row+centerrow][6-col]);

      /*
      switch_kicad = str ( "(at ",pcbX-out_x,          " " ,pcbY-out_y, " " ,-outangle, ")" );
      diode_kicad =  str ( "(at ",pcbX-out_x + diodeX, " " ,pcbY-out_y +diodeY, " " , 90 - outangle, ")" );
      led_kicad =    str ( "(at ",pcbX-out_x + ledX,   " " ,pcbY-out_y +ledY , " " ,- outangle, ")" );
      */

      echo("L",6-col, row+centerrow, SwS,pcbX-out_x,pcbY-out_y, -outangle, DiS, pcbX-out_x + diodeX,pcbY-out_y + diodeY,  90 - outangle, LeS, pcbX-out_x + ledX,pcbY-out_y + ledY , -outangle);

  }

}

// pcb cutouts for the solder pins of an MCU. 
module do_mcu_under(angle) {

  for (y = [ -7.62, 7.62 ]) {
    hull() {
      for (x = [ -14, 14 ])
        translate([ x, y ]) circle(r = 3.25 / 2);
    }
  }
}


// PCB layer footprint of a choc switch. 
module do_choc_under() {

  hull() {

    circle(r = 3.7 / 2); // stem

    translate([ -5.5, 0, 0 ]) // left peg
        circle(r = 2 / 2);

    hull() { // link connectors connector
      translate([ -5, -3.75 ]) circle(r = 3.5 / 2);

      translate([ 0, -5.95 ]) circle(r = 3.5 / 2);
    }
    translate([ -5, -3.75 ]) square([ 4.8, 5 ], center = true);

    translate([ 0, -5.95 ]) square([ 4.4, 5 ], center = true);
  }

  /*	pcb mount choc pin. Remove if not needed
          translate([5.5,0,0])
                  circle(r=1.9/2);
  */

  // choc mount
  translate([ -8.275, -3.8 ]) // pad left
      square([ 2.8, 2.8 ], center = true);
  translate([ 3.275, -5.95 ]) // pad right
      square([ 2.8, 2.8 ], center = true);
}


module do_mcu(a) {
  // Pro micro size
  color("blue") translate([ 0, -4 + 66 - mcu_y / 2, 0 ]) { // board+diameter
    rotate(a) hull() for (ix = [ -1, 1 ]) for (iy = [ -1, 1 ])
        translate([ ix * mcu_x / 2, iy * mcu_y / 2, 0 ]) circle(r = 0.1);
  }
}

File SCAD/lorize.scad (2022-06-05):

include <part-POS.scad>;
include <lorize-desktop.scad>;
include <lorize-keyfuncs.scad>;


$fn = 30;

angle = 14; // Total opening angle
splita = angle / 2;
colstep = 18.75;   // horizontal center to center distance between switches
rowstep = 17.1; // ibid, vertical
m3 = 3.1 / 2;   // radius of m3 hole
centerrow=2; // which row is 0 in the middle of a column. 
/* [Hole Type:] */
// Pick layer to set hole type. 0 = debug, 1 = switchplate
layer = 0; // [0:caps_debug, 1:switchplate, 2:pcb_frame, 3:pcb_shim, 4:palm_mid,
           // 5: palm_rest]


/* [ Board Type:] */
board = 0; // [ 1:maxreform, 2:reform, 0:desktop, 3:smallreform_thumb]



module rtate(x, y, a) {
  newx = x * cos(a) - y * sin(a);
  newy = x * sin(a) + y * cos(a);
}

///  PCB Size 
reform_pcbx = 275.9;
reform_pcby = 102.24;

// mcu board size
mcu_x = 33;   // pro micro 33, feather 51, bluepill 53, weact blackpill 52
mcu_y = 19; // pro micro 19 /bluepill 22.6, weact blackpill 21, roboyn blackpill 18.5 / feather 23
mcu_z = 8;



/// values used to match board types 
desktop = 0;           // 60% best overall ergos, custom PCB shape.
maxreform = 1;         // option with as many keys as we can cram in.
reform = 2;            // 60% that fits well enough for a reform sized PCB
smallreform_thumb = 3; // 30% option with more thumbs for reform.
long = 1;              // used to flag if switch has long or standard cap.

// enum of values used for cdomparison. 
caps_debug = 0;
switchplate = 1;
pcb_frame = 2;
palm_mid = 4;
palm_rest = 5;


// lookup table used for the debugkey function to map col, row to a footprint name in kicad. 
switch_layout = [ // layout for switches & diodes
[ "72",   "5", "11","17", "23", "29", "35", "41", "47", "53", "59", "65", "71","73"], // top row, row4
[ "",   "4", "10","16", "22", "28", "34", "40", "46", "52", "58", "64", "70"],
[ "",   "3", "9", "15", "21", "27", "33", "39", "45", "51", "57", "63", "69"],
[ "",   "2", "8", "14", "20", "26", "32", "38", "44", "50", "56", "62", "68"], // row 1
[ "", "1", "7", "13", "19", "25", "31", "37", "43", "49", "55", "61", "67"], // row 0
];

led_layout = [ // layout for LEDs, which is based on contiguous verticals
[ "",   "84", "93","94", "103", "104", "113", "114", "123", "134", "143", "144", "153"], // top row, row4
[ "",   "85", "92","95", "102", "105", "112", "115", "122", "135", "142", "145", "152"],
[ "",   "86", "91", "96", "101", "106", "111", "116", "121", "136", "141", "146", "151"],
[ "",   "87", "90", "97", "100", "107", "110", "117", "120", "137", "140", "147", "150"], // row 1
[ "",   "88", "89", "98", "99", "108", "109", "118", "119", "138", "139", "148", "149"], // 
];




//// Functions


module do_both_sides(angles, vfudge, hfudge, rowlow, rowhi, separation) {
  for (m=[1,0]) {
    mirror([ m, 0, 0 ])
      doright(angles, vfudge, hfudge, rowlow, rowhi, separation, m);
  }
}

module do_reform_pcb() {

  union() {
    square([ reform_pcbx, reform_pcby ], center = true);
    translate([ 0, +10.92 ])
        square([ reform_pcbx - 2 * 33.510, reform_pcby ], center = true);
  }
}


//  Punch out one half of the shape.
module doright(angles, vfudge, hfudge, rowlow, rowhi, separation, is_mirror) {
  for (x = [1:5]) { // starting with middle finger towards pinky, 

    for (y = [rowlow[x]:rowhi[x]]) {
      debugkey((x - 2) * colstep, 0, splita, hfudge[x], vfudge[x] + (y)*rowstep,
               angles[x], separation, 0, 0, is_mirror, x,y );
    }

    // for cols 5 & 6 we add non-matrix keys. 
    if (5 == x) { // pinky shift key is special.
      if (board ==  smallreform_thumb) { // why can't the laptop have a big key too?
        debugkey(1 + (x - 2) * colstep, 0, splita, -0.5,
                 vfudge[x] + (-1) * rowstep, angles[x], separation, 0, 0,
                 is_mirror,x,-1);
      } else {
      // shiftkey
       debugkey((x - 2 + 0.3) * colstep, 0, splita, -0.75,
                 vfudge[x] - 0.2+ (-1) * rowstep, angles[x], separation, 1, 0,
                 is_mirror,x,-1);
      }

      // pinky menu / long key
      // small reform uses 1u keys, mostly for aesthetics. others use
      // larger 1.5U
      if (board != smallreform_thumb) {
     	debugkey((colstep * 2.25),0 , splita, 0.5,
                   vfudge[x] - 2 * rowstep -0.1, angles[x], separation, 1,
                 0, is_mirror,4,-centerrow);
      }

      // pinky ctrl key
      if ((board == reform) || board == desktop) {
        debugkey((3.5) * colstep, 0, splita, 0,
                 -1.5 - vfudge[x] - (2) * rowstep, angles[x], separation, 0, 0,
                 is_mirror, x, -centerrow);
      }
    }
  }

  // x=0 index fingers have extra rotation to bring up spacebar y location.
  for (x = 0) {
    for (y = [rowlow[x]:rowhi[x]]) {
      debugkey((x - 2) * colstep, 0, splita, hfudge[x], vfudge[x] + (y)*rowstep,
               angles[x], separation, 0, -splita * 0.55, is_mirror, x, y);
    }
  }

  // Far reach upper pinky keys
  if ((board == maxreform) || (board == reform)) {

    for (x = 6) { // weird pinky keys
      if (board == maxreform || (board == reform)) {
        for (y = [rowlow[x]]) {
          debugkey((x - 2) * colstep, 0, splita,  hfudge[x]- 0.75,
                   vfudge[x] + (y -0.15) * rowstep, angles[x], separation, 0, 90,
                   is_mirror, x,-centerrow);
        }
      }
    }
  }
}


module reform_thumbs(separation,yshift) {

/* /// Inputs x_origin,y_origin, angle of orgin from horizontal, x increment ,y increment,
/// additional angle of column, separation between hands, do_longkey,
/// per_key_rotation, mirror key, col,row
*/

  // inner / proximal / index side
  //echo ("right");
    // less than.5mm below bottom of PCB edge, 
    // X center as close as possible to line of index finger keys. 
*   debugkey(-2 * colstep, -2.5 * rowstep, 0, -1, -1.5-yshift, 0, separation, 0, 90, m, 0,-centerrow );
 debugkey(-2 * colstep, -2.5 * rowstep, 0, 3, -yshift, 0, separation, 0, 110, 0, 0,-centerrow );


  // distal / pinky side
  // rotate inner key 90% because that lets us bring it 2mm closer to pinky side key. 
    // X center as close as possible to line between index keys. 
    // Y as high as possible to allow thumb to hit inner key. 
*    debugkey(-1 * colstep, -2 * rowstep, 0, 1.5-(rowstep-14), -4-yshift, 0, separation, 0, splita-1.25,1, 1,-centerrow);

debugkey(-1 * colstep, -2 * rowstep, 0, 4.5-(rowstep-14), -5-yshift, 0, separation, 0, 110,0, 1,-centerrow);


mirror([1,0,0]) {
  //echo ("Left");
  // inner / proximal / index side
    // less than.5mm below bottom of PCB edge, 
    // X center as close as possible to line of index finger keys. 
*   debugkey(-2 * colstep, -2.5 * rowstep, 0, -1, -1.5-yshift, 0, separation, 0, 90, m, 0,-centerrow );
 debugkey(-2 * colstep, -2.5 * rowstep, 0, 3, -yshift, 0, separation, 0, 110, 1, 0,-centerrow );


  // distal / pinky side
  // rotate inner key 90% because that lets us bring it 2mm closer to pinky side key. 
    // X center as close as possible to line between index keys. 
    // Y as high as possible to allow thumb to hit inner key. 
*    debugkey(-1 * colstep, -2 * rowstep, 0, 1.5-(rowstep-14), -4-yshift, 0, separation, , splita-1.25,1, 1,-centerrow);

debugkey(-1 * colstep, -2 * rowstep, 0, 4.5-(rowstep-14), -5-yshift, 0, separation, 1, 110,1, 1,-centerrow);

}

 }


/*
module desktop_thumbs(separation, yshift1, yshiftL) {

  // thumbs
    debugkey(-2 * colstep, -2.5 * rowstep, 0, -0.75, yshiftL, 0, separation,
             long, 0, 1);

    debugkey(-0.75 * colstep, -2 * rowstep, 0, -1.5, yshift1, 0, separation, 0,
             0, 1);

  mirror([ 1, 0, 0 ]) {
    debugkey(-2 * colstep, -2.5 * rowstep, 0, -0.75, yshiftL, 0, separation, long, 0, 1);

    debugkey(-0.75 * colstep, -2 * rowstep, 0, -1.5, yshift1, 0, separation, 0,
             0, 1);
  }
 }
*/


///////// Main per-board descriptions. 
// Supply the SW or D part names to kicad. Different matrixes will have different layout. 

if (board == reform) {
  /* 60 % board, with 1.5 and 1u keys, thumbs aren't perfect, but work */



echo("Reform Debug","col", "row",  "Switch", "X", "Y", "angle", "Diode", "DiodeX", "DiodeY", "DiodeAngle", "LED", "LedX","Led Y", "Led_A");


  angles = [ -1.5, -1.5, -0.75, 0, -0.75, -1.5, -1.5, -1.5 ]; // inner to outer(pinky)
  vfudge = [ 2.5, 1, 0, 0, 0, -0.5, -0.5 ];         // inner to outer
  hfudge = [ -0.5, -0.5, -.33, 0, 0, .6, 0.25 ];

  rowlow = [ -1, -1, -2, -2, -1, 0, 2 ];
  rowhi = [ 2, 2, 2, 2, 2, 2, 2 ];

  pcbx = reform_pcbx;
  pcby = reform_pcby;
  pcb_y_shift = -1; // manually move center of board up/down in relation to center of switches. 

  difference() {
    translate([ 0, pcb_y_shift, 0 ]) do_reform_pcb();

    separation = 53;

    do_both_sides(angles, vfudge, hfudge, rowlow, rowhi, separation);

    // thumbs

    reform_thumbs(separation, pcb_y_shift);

   * translate ([0,-1,0])
    		do_mcu(0);
  }
}
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

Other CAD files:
reform2-keyboard-pcb/3d-models/Kailh_keycap-switch_system_1-5x1.step
SCAD/part-POS.scad

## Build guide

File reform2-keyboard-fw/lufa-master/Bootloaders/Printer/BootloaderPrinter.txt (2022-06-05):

/** \file
 *
 *  This file contains special DoxyGen information for the generation of the main page and other special
 *  documentation pages. It is not a project source file.
 */

/** \mainpage Printer Class USB AVR Bootloader
 *
 *  \section Sec_Compat Demo Compatibility:
 *
 *  The following list indicates what microcontrollers are compatible with this demo.
 *
 *  \li Series 7 USB AVRs (AT90USBxxx7)
 *  \li Series 6 USB AVRs (AT90USBxxx6)
 *  \li Series 4 USB AVRs (ATMEGAxxU4)
 *  \li Series 2 USB AVRs (AT90USBxx2, ATMEGAxxU2)
 *
 *  \section Sec_Info USB Information:
 *
 *  The following table gives a rundown of the USB utilization of this demo.
 *
 *  <table>
 *   <tr>
 *    <td><b>USB Mode:</b></td>
 *    <td>Device</td>
 *   </tr>
 *   <tr>
 *    <td><b>USB Class:</b></td>
 *    <td>Printer Class</td>
 *   </tr>
 *   <tr>
 *    <td><b>USB Subclass:</b></td>
 *    <td>Printer Subclass</td>
 *   </tr>
 *   <tr>
 *    <td><b>Relevant Standards:</b></td>
 *    <td>USBIF Printer Class Standard</td>
 *   </tr>
 *   <tr>
 *    <td><b>Supported USB Speeds:</b></td>
 *    <td>Full Speed Mode</td>
 *   </tr>
 *  </table>
 *
 *  \section Sec_Description Project Description:
 *
 *  This bootloader enumerates to the host as a Generic Text Only Printer device, capable of reading and parsing
 *  "printed" plain-text Intel HEX files to load firmware onto the AVR.
 *
 *  Out of the box this bootloader builds for the AT90USB1287 with an 8KB bootloader section size, and will fit
 *  into 4KB of bootloader space. If you wish to alter this size and/or change the AVR model, you will need to
 *  edit the MCU, FLASH_SIZE_KB and BOOT_SECTION_SIZE_KB values in the accompanying makefile.
 *
 *  When the bootloader is running, the board's LED(s) will flash at regular intervals to distinguish the
 *  bootloader from the normal user application.
 *
 *  \section Sec_Running Running the Bootloader
 *
 *  On the USB AVR8 devices, setting the \c HWBE device fuse will cause the bootloader to run if the \c HWB pin of
 *  the AVR is grounded when the device is reset.
 *
 *  The are two behaviours of this bootloader, depending on the device's fuses:
 *
 *  <b>If the device's BOOTRST fuse is set</b>, the bootloader will run any time the system is reset from
 *  the external reset pin, unless no valid user application has been loaded. To initiate the bootloader, the
 *  device's external reset pin should be grounded momentarily.
 *
 *  <b>If the device's BOOTRST fuse is not set</b>, the bootloader will run only if initiated via a software
 *  jump, or if the \c HWB pin was low during the last device reset (if the \c HWBE fuse is set).
 *
 *  For board specific exceptions to the above, see below.
 *
 *  \subsection SSec_XPLAIN Atmel Xplain Board
 *  Ground the USB AVR JTAG's \c TCK pin to ground when powering on the board to start the bootloader. This assumes the
 *  \c HWBE fuse is cleared and the \c BOOTRST fuse is set as the HWBE pin is not user accessible on this board.
 *
 *  \subsection SSec_Leonardo Arduino Leonardo Board
 *  Ground \c IO13 when powering the board to start the bootloader. This assumes the \c HWBE fuse is cleared and the
 *  \c BOOTRST fuse is set as the HWBE pin is not user accessible on this board.
 *
 *  \section Sec_Installation Driver Installation
 *
 *  This bootloader uses the Generic Text-Only printer drivers inbuilt into all modern operating systems, thus no
 *  additional drivers need to be supplied for correct operation.
 *
 *  \section Sec_HostApp Host Controller Application
 *
 *  This bootloader is compatible with Notepad under Windows, and the command line \c lpr utility under Linux.
 *
 *  \subsection SSec_Notepad Notepad (Windows)
 *
 *  While most text applications under Windows will be compatible with the bootloader, the inbuilt Notepad utility
 *  is recommended as it will introduce minimal formatting changes to the output stream. To program with Notepad,
 *  open the target HEX file and print it to the Generic Text Only printer device the bootloader creates.
 *
 *  \subsection SSec_LPR LPR (Linux)
 *
 *  While the CUPS framework under Linux will enumerate the bootloader as a Generic Text-Only printer, many
 *  applications will refuse to print to the device due to the lack of rich formatting options available. As a result,
 *  under Linux HEX files must be printed via the low level \c lpr utility instead.
 *
 *  \code
 *  cat Mouse.hex | lpr
 *  \endcode
 *
 *  \section Sec_API User Application API
 *
 *  Several user application functions for FLASH and other special memory area manipulations are exposed by the bootloader,
 *  allowing the user application to call into the bootloader at runtime to read and write FLASH data.
 *
 *  By default, the bootloader API jump table is located 32 bytes from the end of the device's FLASH memory, and follows the
 *  following layout:
 *
 *  \code
 *  #define BOOTLOADER_API_TABLE_SIZE          32
 *  #define BOOTLOADER_API_TABLE_START         ((FLASHEND + 1UL) - BOOTLOADER_API_TABLE_SIZE)
 *  #define BOOTLOADER_API_CALL(Index)         (void*)((BOOTLOADER_API_TABLE_START + (Index * 2)) / 2)
 *
 *  void    (*BootloaderAPI_ErasePage)(uint32_t Address)               = BOOTLOADER_API_CALL(0);
 *  void    (*BootloaderAPI_WritePage)(uint32_t Address)               = BOOTLOADER_API_CALL(1);
 *  void    (*BootloaderAPI_FillWord)(uint32_t Address, uint16_t Word) = BOOTLOADER_API_CALL(2);
 *  uint8_t (*BootloaderAPI_ReadSignature)(uint16_t Address)           = BOOTLOADER_API_CALL(3);
 *  uint8_t (*BootloaderAPI_ReadFuse)(uint16_t Address)                = BOOTLOADER_API_CALL(4);
 *  uint8_t (*BootloaderAPI_ReadLock)(void)                            = BOOTLOADER_API_CALL(5);
 *  void    (*BootloaderAPI_WriteLock)(uint8_t LockBits)               = BOOTLOADER_API_CALL(6);
 *
 *  #define BOOTLOADER_MAGIC_SIGNATURE_START   (BOOTLOADER_API_TABLE_START + (BOOTLOADER_API_TABLE_SIZE - 2))
 *  #define BOOTLOADER_MAGIC_SIGNATURE         0xDCFB
 *
 *  #define BOOTLOADER_CLASS_SIGNATURE_START   (BOOTLOADER_API_TABLE_START + (BOOTLOADER_API_TABLE_SIZE - 4))
 *  #define BOOTLOADER_PRINTER_SIGNATURE       0xDF20
 *
 *  #define BOOTLOADER_ADDRESS_START           (BOOTLOADER_API_TABLE_START + (BOOTLOADER_API_TABLE_SIZE - 8))
 *  #define BOOTLOADER_ADDRESS_LENGTH          4
 *  \endcode
 *
 *  From the application the API support of the bootloader can be detected by reading the FLASH memory bytes located at address
 *  \c BOOTLOADER_MAGIC_SIGNATURE_START and comparing them to the value \c BOOTLOADER_MAGIC_SIGNATURE. The class of bootloader
 *  can be determined by reading the FLASH memory bytes located at address \c BOOTLOADER_CLASS_SIGNATURE_START and comparing them
 *  to the value \c BOOTLOADER_PRINTER_SIGNATURE. The start address of the bootloader can be retrieved by reading the bytes of FLASH
 *  memory starting from address \c BOOTLOADER_ADDRESS_START.
 *
 *  \subsection SSec_API_MemLayout Device Memory Map
 *  The following illustration indicates the final memory map of the device when loaded with the bootloader.
 *
 *  \verbatim
 *  +----------------------------+ 0x0000
 *  |                            |
 *  |                            |
 *  |                            |
 *  |                            |
 *  |                            |
 *  |                            |
 *  |                            |
 *  |                            |
 *  |      User Application      |
 *  |                            |
 *  |                            |
 *  |                            |
 *  |                            |
 *  |                            |
 *  |                            |
 *  |                            |
 *  +----------------------------+ FLASHEND - BOOT_SECTION_SIZE
 *  |                            |
 *  |   Bootloader Application   |
 *  | (Not User App. Accessible) |
 *  |                            |
 *  +----------------------------+ FLASHEND - 96
 *  |   API Table Trampolines    |
 *  | (Not User App. Accessible) |
 *  +----------------------------+ FLASHEND - 32
 *  |    Bootloader API Table    |
 *  |   (User App. Accessible)   |
 *  +----------------------------+ FLASHEND - 8
 *  |   Bootloader ID Constants  |
 *  |   (User App. Accessible)   |
 *  +----------------------------+ FLASHEND
 *  \endverbatim
 *
 *
 *  \section Sec_KnownIssues Known Issues:
 *
 *  \par On Linux machines, new firmware fails to be sent to the device via CUPS.
 *  Only a limited subset of normal printer functionality is exposed via the
 *  bootloader, causing CUPS to reject print requests from applications that
 *  are unable to handle true plain-text printing. For best results, the low
 *  level \c lpr command should be used to print new firmware to the bootloader.
 *
 *  \section Sec_Options Project Options
 *
 *  The following defines can be found in this demo, which can control the demo behaviour when defined, or changed in value.
 *
 *  <table>
 *   <tr>
 *    <td>
 *     None
 *    </td>
 *   </tr>
 *  </table>
 */

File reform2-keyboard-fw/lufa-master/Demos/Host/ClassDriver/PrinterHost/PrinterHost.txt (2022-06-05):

/** \file
 *
 *  This file contains special DoxyGen information for the generation of the main page and other special
 *  documentation pages. It is not a project source file.
 */

/** \mainpage Printer Host Demo
 *
 *  \section Sec_Compat Demo Compatibility:
 *
 *  The following list indicates what microcontrollers are compatible with this demo.
 *
 *  \li Series 7 USB AVRs (AT90USBxxx7)
 *
 *  \section Sec_Info USB Information:
 *
 *  The following table gives a rundown of the USB utilization of this demo.
 *
 *  <table>
 *   <tr>
 *    <td><b>USB Mode:</b></td>
 *    <td>Host</td>
 *   </tr>
 *   <tr>
 *    <td><b>USB Class:</b></td>
 *    <td>Printer Device</td>
 *   </tr>
 *   <tr>
 *    <td><b>USB Subclass:</b></td>
 *    <td>Bidirectional Protocol</td>
 *   </tr>
 *   <tr>
 *    <td><b>Relevant Standards:</b></td>
 *    <td>USBIF Printer Class Specification \n
 *        PCL Language Specification</td>
 *   </tr>
 *   <tr>
 *    <td><b>Supported USB Speeds:</b></td>
 *    <td>Low Speed Mode \n
 *        Full Speed Mode</td>
 *   </tr>
 *  </table>
 *
 *  \section Sec_Description Project Description:
 *
 *  Printer host demonstration application. This gives a simple reference
 *  application for implementing a USB Printer host, for USB printers using
 *  the bidirectional data encapsulation protocol and PCL language.
 *
 *  Upon connection of a compatible printer, the printer's device ID is sent
 *  to the AVR's serial port, and a simple test page is printed using the PCL
 *  printer language.
 *
 *  \section Sec_Options Project Options
 *
 *  The following defines can be found in this demo, which can control the demo behaviour when defined, or changed in value.
 *
 *  <table>
 *   <tr>
 *    <td>
 *     None
 *    </td>
 *   </tr>
 *  </table>
 */

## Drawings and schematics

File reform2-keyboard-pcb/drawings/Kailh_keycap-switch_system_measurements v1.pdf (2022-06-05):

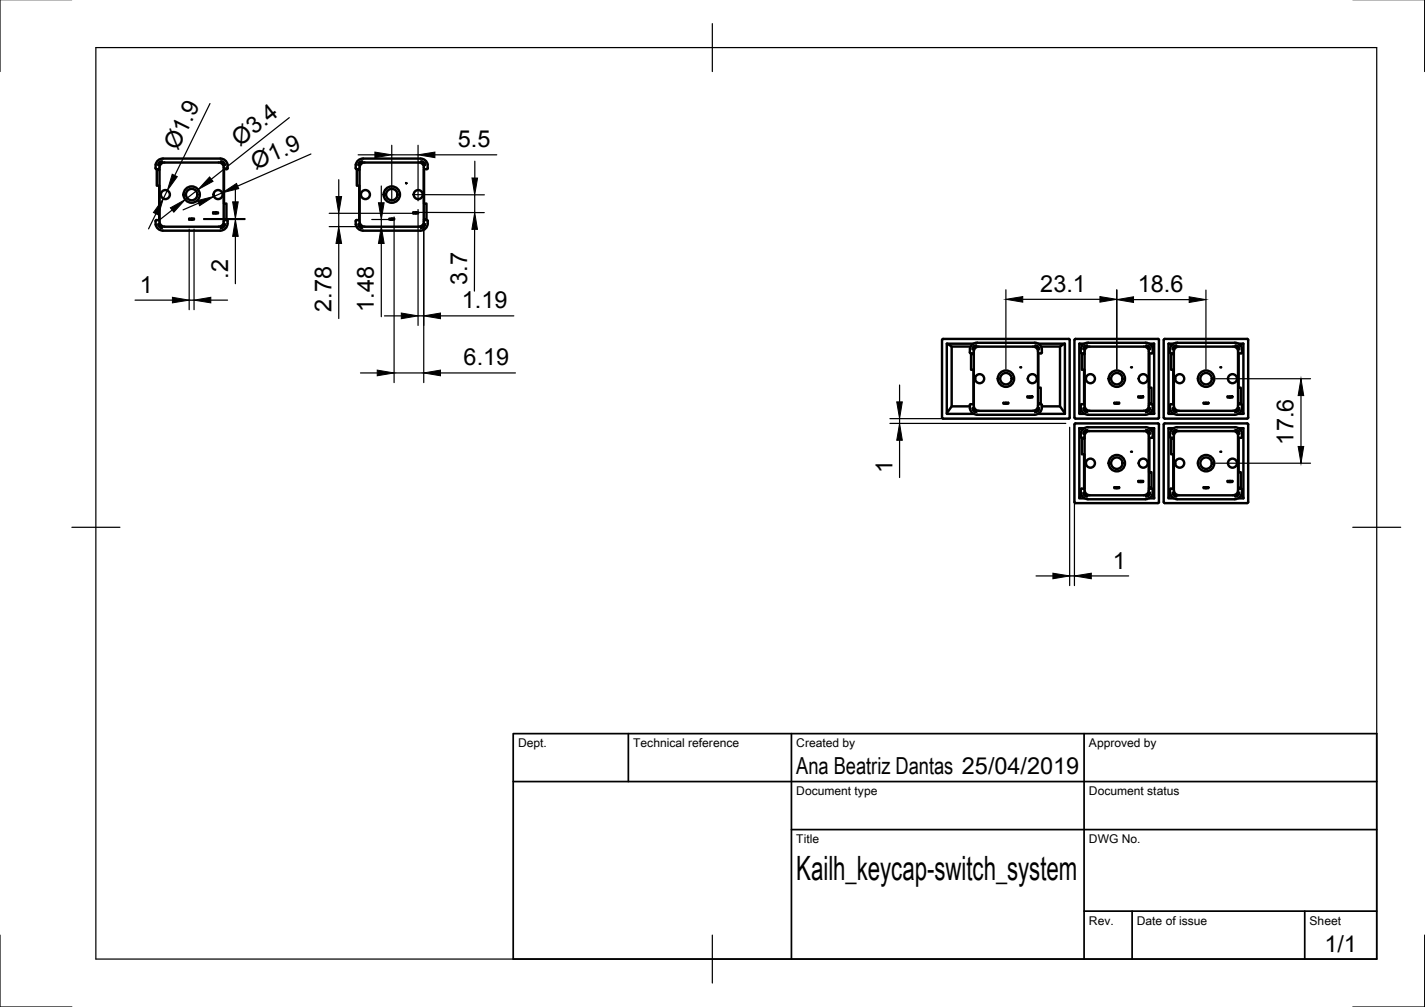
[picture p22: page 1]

Dept. | Technical reference | Created by Ana Beatriz Dantas 25/04/2019 | Approved by

Document type | Document status

Title Kailh_keycap-switch_system | DWG No.

Rev. | Date of issue | Sheet 1/1

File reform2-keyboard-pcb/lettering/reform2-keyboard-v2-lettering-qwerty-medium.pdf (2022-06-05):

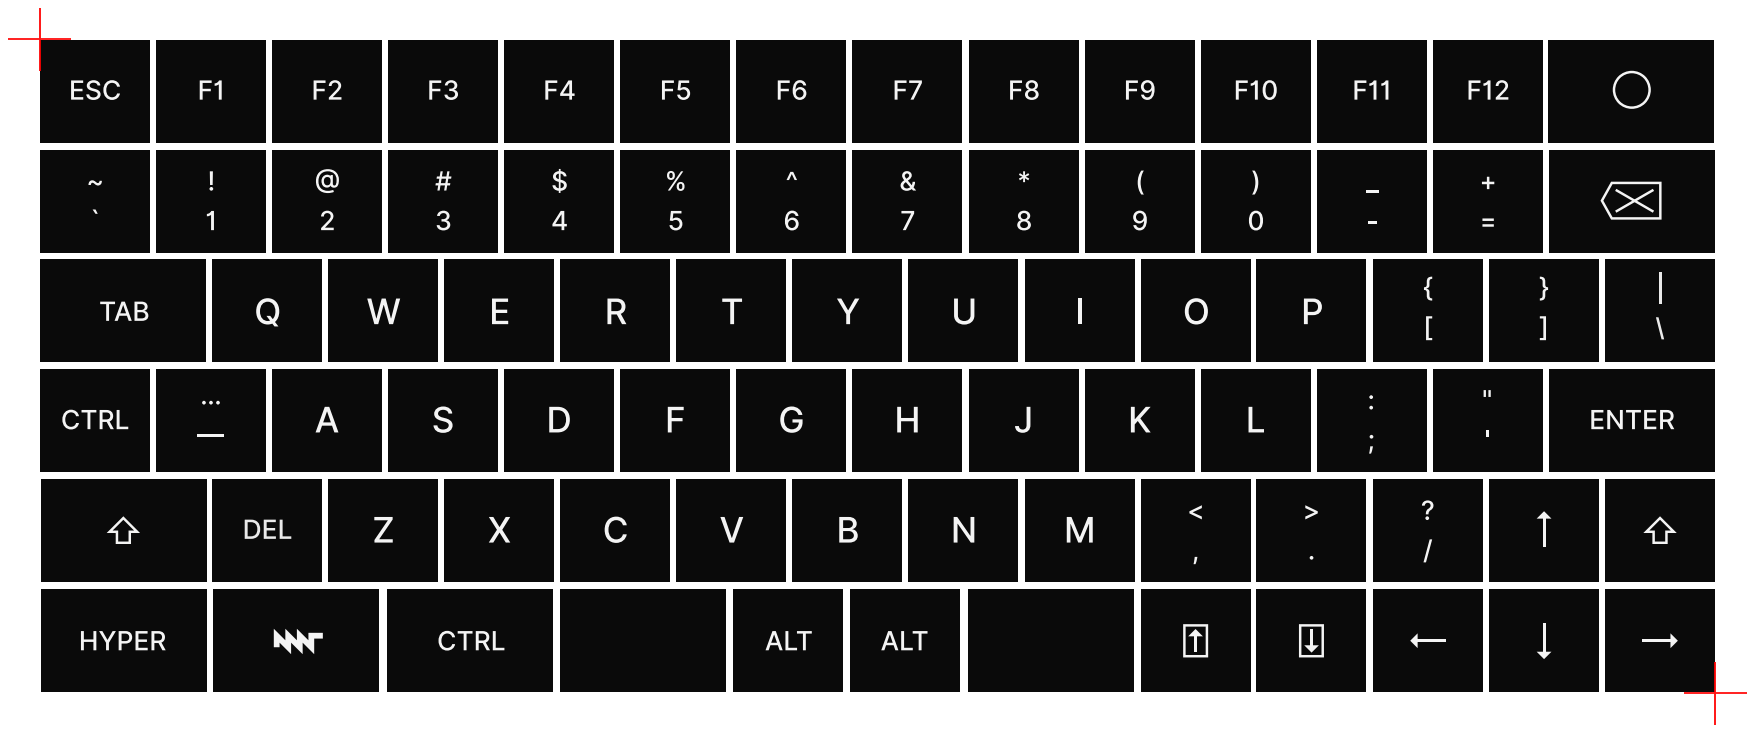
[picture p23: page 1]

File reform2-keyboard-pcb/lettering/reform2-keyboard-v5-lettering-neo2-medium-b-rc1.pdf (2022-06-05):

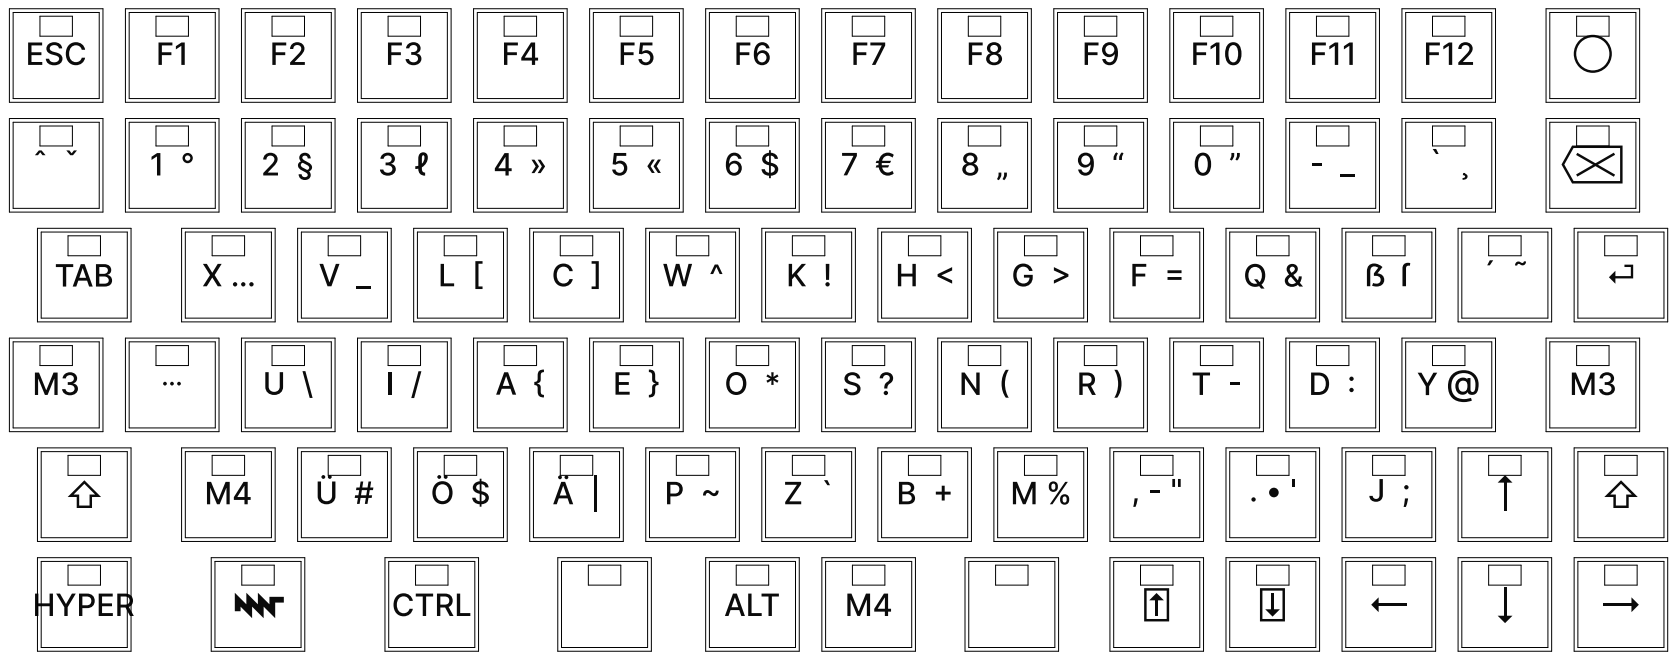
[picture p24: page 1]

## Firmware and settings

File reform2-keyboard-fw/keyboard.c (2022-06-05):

/*
  MNT Reform 2.0 Keyboard Firmware
  Copyright 2019-2021  Lukas F. Hartmann / MNT Research GmbH, Berlin (lukas@mntre.com)
  And Contributors:
  Chartreuse
  V Körbes
  Robey Pointer (robey@lag.net)

  Based on code from LUFA Library (lufa-lib.org):
  Copyright 2018 Dean Camera (dean [at] fourwalledcubicle [dot] com)

  SPDX-License-Identifier: MIT

  Ergo Keyboard additions Copyright 2022, milestogo. released under the same MIT license. 

*/

#include <stdlib.h>
#include <avr/io.h>
#ifndef KBD_VARIANT_ERGO
#include "backlight.h"
#endif
// Important: version and variant info moved here
#include "constants.h"
#include "hid_report.h"
#include "keyboard.h"
#include "menu.h"
#include "oled.h"
#include "powersave.h"
#include "remote.h"
#include "scancodes.h"

#ifdef KBD_VARIANT_V
#include "matrix_v.h"
#endif

#ifdef KBD_VARIANT_ERGO
#include "matrix_ergo.h"
#else
#include "matrix.h"
#endif

/** Buffer to hold the previously generated Keyboard HID report, for comparison purposes inside the HID class driver. */
static uint8_t PrevKeyboardHIDReportBuffer[sizeof(USB_KeyboardReport_Data_t)];
static uint8_t PrevMediaControlHIDReportBuffer[sizeof(USB_MediaReport_Data_t)];

/** LUFA HID Class driver interface configuration and state information. This structure is
 *  passed to all HID Class driver functions, so that multiple instances of the same class
 *  within a device can be differentiated from one another.
 */
USB_ClassInfo_HID_Device_t Keyboard_HID_Interface =
  {
    .Config =
      {
        .InterfaceNumber              = INTERFACE_ID_Keyboard,
        .ReportINEndpoint             =
          {
            .Address              = KEYBOARD_EPADDR,
            .Size                 = HID_EPSIZE,
            .Banks                = 1,
          },
        .PrevReportINBuffer           = PrevKeyboardHIDReportBuffer,
        .PrevReportINBufferSize       = sizeof(PrevKeyboardHIDReportBuffer),
      },
  };

/** LUFA HID Class driver interface configuration and state information for the Media Controller */
USB_ClassInfo_HID_Device_t MediaControl_HID_Interface =
  {
    .Config =
      {
        .InterfaceNumber              = INTERFACE_ID_MediaControl,
        .ReportINEndpoint             =
          {
            .Address              = MEDIACONTROL_EPADDR,
            .Size                 = HID_EPSIZE,
            .Banks                = 1,
          },
        .PrevReportINBuffer           = PrevMediaControlHIDReportBuffer,
        .PrevReportINBufferSize       = sizeof(PrevMediaControlHIDReportBuffer),
      },
  };

uint8_t matrix_debounce[KBD_COLS*KBD_ROWS];
uint8_t matrix_state[KBD_COLS*KBD_ROWS];

int active_meta_mode = 0;
uint8_t last_meta_key = 0;

uint8_t* active_matrix = matrix;
bool media_toggle = 0;
bool fn_key = 0; // Am I holding FN?
bool circle = 0; // Am I holding circle?

// enter the menu
void enter_meta_mode(void) {
  active_meta_mode = 1;
  reset_and_render_menu();
}

void reset_keyboard_state(void) {
  for (int i = 0; i < KBD_COLS*KBD_ROWS; i++) {
    matrix_debounce[i] = 0;
    matrix_state[i] = 0;
  }
  last_meta_key = 0;
}

inline bool is_media_key(uint8_t keycode) {
  return (keycode>=HID_KEYBOARD_SC_MEDIA_PLAY);
}

bool get_media_keys(uint8_t keycode, USB_MediaReport_Data_t* mcr) {
  bool media_key = false;
  if (keycode == HID_KEYBOARD_SC_MEDIA_MUTE) {
    if (mcr) mcr->Mute = 1;
    media_key = true;
  } else if (keycode == HID_KEYBOARD_SC_MEDIA_VOLUME_UP) {
    if (mcr) mcr->VolumeUp = 1;
    media_key = true;
  } else if (keycode == HID_KEYBOARD_SC_MEDIA_VOLUME_DOWN) {
    if (mcr) mcr->VolumeDown = 1;
    media_key = true;
  } else if (keycode == HID_KEYBOARD_SC_MEDIA_BACKWARD) {
    if (mcr) mcr->PreviousTrack = 1;
    media_key = true;
  } else if (keycode == HID_KEYBOARD_SC_MEDIA_FORWARD) {
    if (mcr) mcr->NextTrack = 1;
    media_key = true;
  } else if (keycode == HID_KEYBOARD_SC_MEDIA_PLAY) {
    if (mcr) mcr->PlayPause = 1;
    media_key = true;
  }
  return media_key;
}

#define MAX_SCANCODES 6
static uint8_t pressed_scancodes[MAX_SCANCODES] = {0,0,0,0,0,0};

// usb_report_mode: if you pass 0, you can leave KeyboardReport NULL
int process_keyboard(uint8_t* resulting_scancodes) {
  // how many keys are pressed this round
  uint8_t total_pressed = 0;
  uint8_t used_key_codes = 0;

  // pull ROWs low one after the other
  for (int y = 0; y < KBD_ROWS; y++) {
    switch (y) {
#ifdef KBD_VARIANT_ERGO
    case 0: output_low(PORTE, 6); break;
    case 1: output_low(PORTB, 5); break;
    case 2: output_low(PORTB, 6); break;
    case 3: output_low(PORTB, 7); break;
    case 4: output_low(PORTD, 6); break;
    case 5: output_low(PORTC, 7); break;

#else // factory default
    case 0: output_low(PORTB, 6); break;
    case 1: output_low(PORTB, 5); break;
    case 2: output_low(PORTB, 4); break;
    case 3: output_low(PORTD, 7); break;
    case 4: output_low(PORTD, 6); break;
    case 5: output_low(PORTD, 4); break;
#endif
    }

    // wait for signal to stabilize
    // TODO maybe not necessary
   // _delay_us(10);

    // check input COLs
    
  for (int x=0; x<KBD_COLS; x++) {
      uint16_t keycode;
      uint16_t loc = y*KBD_COLS+x;
      keycode = active_matrix[loc];
      uint8_t  pressed = 0;
      uint8_t  debounced_pressed = 0;

      // column pins are all over the place
      switch (x) {
#ifdef KBD_VARIANT_ERGO
      case 0:  pressed = !(PINB&(1<<3)); break;
      case 1:  pressed = !(PINB&(1<<2)); break;
      case 2:  pressed = !(PINB&(1<<1)); break;
      case 3:  pressed = !(PINB&(1<<4)); break;
      case 4:  pressed = !(PIND&(1<<7)); break;
      case 5:  pressed = !(PIND&(1<<4)); break;
      case 6:  pressed = !(PINF&(1<<0)); break;
      case 7:  pressed = !(PINF&(1<<1)); break;
      case 8:  pressed = !(PINF&(1<<4)); break;
      case 9:  pressed = !(PINF&(1<<5)); break;
      case 10: pressed = !(PINF&(1<<6)); break;
      case 11: pressed = !(PINF&(1<<7)); break;
#else // factory default
      case 0:  pressed = !(PIND&(1<<5)); break;
      case 1:  pressed = !(PINF&(1<<7)); break;
      case 2:  pressed = !(PINE&(1<<6)); break;
      case 3:  pressed = !(PINC&(1<<7)); break;
      case 4:  pressed = !(PINB&(1<<3)); break;
      case 5:  pressed = !(PINB&(1<<2)); break;
      case 6:  pressed = !(PINB&(1<<1)); break;
      case 7:  pressed = !(PINB&(1<<0)); break;
      case 8:  pressed = !(PINF&(1<<0)); break;
      case 9:  pressed = !(PINF&(1<<1)); break;
      case 10: pressed = !(PINF&(1<<4)); break;
      case 11: pressed = !(PINF&(1<<5)); break;
      case 12: pressed = !(PINF&(1<<6)); break;
      case 13: pressed = !(PINC&(1<<6)); break;
#endif
      }

      // shift new state as bit into debounce "register"
      matrix_debounce[loc] = (matrix_debounce[loc]<<1)|pressed;

      // if unclear state, we need to keep the last state of the key
      if (matrix_debounce[loc] == 0x00) {
        matrix_state[loc] = 0;
      } else if (matrix_debounce[loc] == 0x01) {
        matrix_state[loc] = 1;
      }
      debounced_pressed = matrix_state[loc];

      if (debounced_pressed) {
        total_pressed++;

#ifdef KBD_VARIANT_ERGO
        if (keycode == KEY_NOP) {
          return 0;
        }

        /// locally shifted keycodes
        if (keycode >= ERGO_SHIFT_LOW && keycode <= ERGO_SHIFT_HI) {
          total_pressed++;
          if (used_key_codes < (MAX_SCANCODES-1) && resulting_scancodes) {
              resulting_scancodes[used_key_codes++] = HID_KEYBOARD_SC_LEFT_SHIFT;
          

          switch (keycode) {
            case KEY_LCBRC: 
              resulting_scancodes[used_key_codes++] = KEY_OPENING_BRACKET_AND_OPENING_BRACE;
              break;

            case KEY_RCBRC:
              resulting_scancodes[used_key_codes++] = KEY_CLOSING_BRACKET_AND_CLOSING_BRACE;
              break;

            case KEY_TILDE:
              resulting_scancodes[used_key_codes++] = KEY_GRAVE_ACCENT_AND_TILDE;
              break;

            case KEY_PIPE:
              resulting_scancodes[used_key_codes++] = KEY_BACKSLASH_AND_PIPE;
              break;

            case KEY_UNDS:
              resulting_scancodes[used_key_codes++] = KEY_MINUS_AND_UNDERSCORE;
              break;

            case KEY_PLUS:
              resulting_scancodes[used_key_codes++] = KEY_EQUAL_AND_PLUS;
              break;

           case KEY_RPRN:
              resulting_scancodes[used_key_codes++] = KEY_0;
              break;

            case KEY_LPRN:
              resulting_scancodes[used_key_codes++] = KEY_9;
              break;

            case KEY_PASTE: // from clipboard
              resulting_scancodes[used_key_codes++] = KEY_INSERT;
              break;
            }
          }
        }

        /// locally controlled keycodes
        if (keycode >= ERGO_CTRL_LOW && keycode <= ERGO_CTRL_HI) {
          total_pressed++;
          if (used_key_codes < (MAX_SCANCODES-1) && resulting_scancodes) {
              resulting_scancodes[used_key_codes++] =  HID_KEYBOARD_SC_RIGHT_CONTROL;

          switch (keycode) {
            case KEY_ALL: 
              resulting_scancodes[used_key_codes++] = KEY_A;
              break;

            case KEY_KILL:
              resulting_scancodes[used_key_codes++] = KEY_K;
              break;

            case KEY_CUT: // to clipboard
              resulting_scancodes[used_key_codes++] = KEY_DELETE;
              break;

            case KEY_COPY: // to clipboard
              resulting_scancodes[used_key_codes++] = KEY_INSERT;
              break;

             case KEY_TMUX:
              resulting_scancodes[used_key_codes++] = KEY_B;
              break;
 
            case KEY_WORDF:   // alt arrow is used by terminal console bindings, so use ctrl version. 
                            // this may be terminal dependant.  
              resulting_scancodes[used_key_codes++] = HID_KEYBOARD_SC_RIGHT_ARROW;
              break;

            case KEY_WORDB:
              resulting_scancodes[used_key_codes++] = HID_KEYBOARD_SC_LEFT_ARROW;
              break;

            case KEY_DELWF:
              resulting_scancodes[used_key_codes++] = KEY_DELETE;
              break;

            case KEY_DELWB:
              resulting_scancodes[used_key_codes++] = KEY_W;
              break;
            }
          }
        }


        /// locally ALTed keycodes
        if (keycode >= ERGO_ALT_LOW && keycode <= ERGO_ALT_HI) {
          total_pressed++;
          if (used_key_codes < (MAX_SCANCODES-1) && resulting_scancodes) {
              resulting_scancodes[used_key_codes++] = HID_KEYBOARD_SC_LEFT_ALT;
      
         switch (keycode) {
            case KEY_NOP:
              resulting_scancodes[used_key_codes++] = KEY_1;
              break;
            }
          }
        }


#endif

        // Is circle key pressed?
        if (keycode == KEY_CIRCLE) {
          if (fn_key) {
            circle = 1;
          } else {
            if (!active_meta_mode && !last_meta_key) {
              enter_meta_mode();
            }
          }
        } else if (keycode == HID_KEYBOARD_SC_EXECUTE) {
          fn_key = 1;
          active_matrix = matrix_fn;
        } else {
          if (active_meta_mode) {
            // not holding the same key?
            if (last_meta_key != keycode) {
              // hyper/circle/menu functions
              int stay_meta = execute_meta_function(keycode);
              // don't repeat action while key is held down
              last_meta_key = keycode;

              // exit meta mode
              if (!stay_meta) {
                active_meta_mode = 0;
              }

              // after wake-up from sleep mode, skip further keymap processing
              if (stay_meta == 2) {
                reset_keyboard_state();
                enter_meta_mode();
                return 0;
              }
            }
          } else if (!last_meta_key) {
            // not meta mode, regular key: report keypress via USB
            // 6 keys is the limit in the HID descriptor
            if (used_key_codes < MAX_SCANCODES && resulting_scancodes) {
              resulting_scancodes[used_key_codes++] = keycode;
            }
          }
        }
      } else {
        // key not pressed
        if (keycode == HID_KEYBOARD_SC_EXECUTE) {
          fn_key = 0;
          if (media_toggle) {
            active_matrix = matrix_fn_toggled;
          } else {
            active_matrix = matrix;
          }
        } else if (keycode == KEY_CIRCLE) {
          if (fn_key && circle) {
            if (!media_toggle) {
              media_toggle = 1;
              active_matrix = matrix_fn_toggled;
            } else {
              media_toggle = 0;
              active_matrix = matrix_fn;
            }
          }
          circle = 0;
        }
      }
    }

    switch (y) {
#ifdef KBD_VARIANT_ERGO
    case 0: output_high(PORTE, 6); break;
    case 1: output_high(PORTB, 5); break;
    case 2: output_high(PORTB, 6); break;
    case 3: output_high(PORTB, 7); break;
    case 4: output_high(PORTD, 6); break;
    case 5: output_high(PORTC, 7); break;
  
#else // factory default
    case 0: output_high(PORTB, 6); break;
    case 1: output_high(PORTB, 5); break;
    case 2: output_high(PORTB, 4); break;
    case 3: output_high(PORTD, 7); break;
    case 4: output_high(PORTD, 6); break;
    case 5: output_high(PORTD, 4); break;
#endif
    }
  }

  // if no more keys are held down, allow a new meta command
  if (total_pressed<1) last_meta_key = 0;

  return used_key_codes;
}

int main(void)
{
#ifdef KBD_VARIANT_QWERTY_US
  matrix[KBD_COLS*4+1]=KEY_DELETE;
#endif
#ifdef KBD_VARIANT_NEO2
  matrix[KBD_COLS*3+0]=HID_KEYBOARD_SC_CAPS_LOCK; // M3
  matrix[KBD_COLS*2+13]=KEY_ENTER;
  matrix[KBD_COLS*3+13]=KEY_BACKSLASH_AND_PIPE; // M3
#endif

  setup_hardware();
  GlobalInterruptEnable();
  anim_hello();

  int counter = 0;

  for (;;)
  {
    process_keyboard(NULL);
    HID_Device_USBTask(&Keyboard_HID_Interface);
    HID_Device_USBTask(&MediaControl_HID_Interface);
    USB_USBTask();
    counter++;
#ifndef KBD_VARIANT_STANDALONE
      if (counter>=100000) {
      remote_check_for_low_battery();
        counter = 0;
      }
      if (counter%750 == 0) {
        remote_process_alerts();
      }
#endif
  }
}

void setup_hardware(void)
{
  // Disable watchdog if enabled by bootloader/fuses
  MCUSR &= ~(1 << WDRF);
  wdt_disable();

  // Disable clock division
  clock_prescale_set(clock_div_1);

#ifdef KBD_VARIANT_ERGO
  // declare port pins as inputs (0) and outputs (1)
  // col input, row output
  DDRB  = 0b11100000;
  PORTB = 0b00011110;
  
  DDRC  = 0b11000000;
  PORTC = 0b01000000; // PWM pin on C6eee
  
  DDRD  = 0b01001001; 
  PORTD = 0b10010000;
  
  DDRE  = 0b01000000;
  PORTE = 0b00000000;

  DDRF  = 0b00000000;
  PORTF = 0b11111111; // don't know why F2,3 are masked 


#else // default keyboard
  // declare port pins as inputs (0) and outputs (1)
  DDRB  = 0b11110000;
  DDRC  = 0b00000000;
  DDRD  = 0b11011001;
  DDRE  = 0b00000000;
  DDRF  = 0b00000000;

  // initial pin states
  PORTB = 0b10001111; // B7, PWM key is set to 1??
  PORTC = 0b11000000;
  PORTD = 0b00100000;
  PORTE = 0b01000000;
  PORTF = 0b11111111;

#endif
  // disable JTAG
  MCUCR |=(1<<JTD);
  MCUCR |=(1<<JTD);

#ifndef KBD_VARIANT_ERGO
  kbd_brightness_init();
#endif
  gfx_init(false);
  remote_init();
  USB_Init();
}



ISR(WDT_vect)
{
  // WDT interrupt enable and flag cleared on entry
//  wdt_disable(); // Disable watchdog for now based on https://source.mnt.re/reform/reform/-/merge_requests/26
  Delay_MS(1);
}

/** Event handler for the library USB Connection event. */
void EVENT_USB_Device_Connect(void)
{
}

/** Event handler for the library USB Disconnection event. */
void EVENT_USB_Device_Disconnect(void)
{
}

/** Event handler for the library USB Configuration Changed event. */
void EVENT_USB_Device_ConfigurationChanged(void)
{
  bool ConfigSuccess = true;

  ConfigSuccess &= HID_Device_ConfigureEndpoints(&Keyboard_HID_Interface);
	ConfigSuccess &= HID_Device_ConfigureEndpoints(&MediaControl_HID_Interface);

  USB_Device_EnableSOFEvents();
}

/** Event handler for the library USB Control Request reception event. */
void EVENT_USB_Device_ControlRequest(void)
{
  HID_Device_ProcessControlRequest(&Keyboard_HID_Interface);
  HID_Device_ProcessControlRequest(&MediaControl_HID_Interface);
}

/** Event handler for the USB device Start Of Frame event. */
void EVENT_USB_Device_StartOfFrame(void)
{
  HID_Device_MillisecondElapsed(&Keyboard_HID_Interface);
  HID_Device_MillisecondElapsed(&MediaControl_HID_Interface);
}

/** HID class driver callback function for the creation of HID reports to the host.
 *
 *  \param[in]     HIDInterfaceInfo  Pointer to the HID class interface configuration structure being referenced
 *  \param[in,out] ReportID    Report ID requested by the host if non-zero, otherwise callback should set to the generated report ID
 *  \param[in]     ReportType  Type of the report to create, either HID_REPORT_ITEM_In or HID_REPORT_ITEM_Feature
 *  \param[out]    ReportData  Pointer to a buffer where the created report should be stored
 *  \param[out]    ReportSize  Number of bytes written in the report (or zero if no report is to be sent)
 *
 *  \return Boolean \c true to force the sending of the report, \c false to let the library determine if it needs to be sent
 */

bool CALLBACK_HID_Device_CreateHIDReport(USB_ClassInfo_HID_Device_t* const HIDInterfaceInfo,
                                         uint8_t* const ReportID,
                                         const uint8_t ReportType,
                                         void* ReportData,
                                         uint16_t* const ReportSize)
{
  int num_keys = process_keyboard(pressed_scancodes);
  if (num_keys > MAX_SCANCODES) num_keys = MAX_SCANCODES;

  if (HIDInterfaceInfo == &Keyboard_HID_Interface) {
    // host asks for a keyboard report
    USB_KeyboardReport_Data_t* KeyboardReport = (USB_KeyboardReport_Data_t*)ReportData;
    *ReportSize = sizeof(USB_KeyboardReport_Data_t);
    for (int i=0; i<num_keys; i++) {
      uint8_t sc = pressed_scancodes[i];
      if (!is_media_key(sc)) {
        KeyboardReport->KeyCode[i] = sc;
      }
    }
  } else if (HIDInterfaceInfo == &MediaControl_HID_Interface) {
    // host asks for a media control report
    USB_MediaReport_Data_t* MediaControlReport = (USB_MediaReport_Data_t*)ReportData;
    *ReportSize = sizeof(USB_MediaReport_Data_t);
    for (int i=0; i<num_keys; i++) {
      uint8_t sc = pressed_scancodes[i];
      if (is_media_key(sc)) {
        get_media_keys(sc, MediaControlReport);
      }
    }
  }
  return false;
}

/** HID class driver callback function for the processing of HID reports from the host.
 *
 *  \param[in] HIDInterfaceInfo  Pointer to the HID class interface configuration structure being referenced
 *  \param[in] ReportID    Report ID of the received report from the host
 *  \param[in] ReportType  The type of report that the host has sent, either HID_REPORT_ITEM_Out or HID_REPORT_ITEM_Feature
 *  \param[in] ReportData  Pointer to a buffer where the received report has been stored
 *  \param[in] ReportSize  Size in bytes of the received HID report
 */
void CALLBACK_HID_Device_ProcessHIDReport(USB_ClassInfo_HID_Device_t* const HIDInterfaceInfo,
                                          const uint8_t ReportID,
                                          const uint8_t ReportType,
                                          const void* ReportData,
                                          const uint16_t ReportSize)
{
  uint8_t* data = (uint8_t*)ReportData;
  if (ReportSize<4) return;

  hid_report_cmd(data);
}

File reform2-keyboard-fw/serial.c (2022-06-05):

/*
NewSoftSerial.cpp 
Multi-instance software serial library for Arduino/Wiring
-- Interrupt-driven receive and other improvements by ladyada
   (http://ladyada.net)
-- Tuning, circular buffer, derivation from class Print/Stream,
   multi-instance support, porting to 8MHz processors,
   various optimizations, PROGMEM delay tables, inverse logic and 
   direct port writing by Mikal Hart (http://www.arduiniana.org)
-- Pin change interrupt macros by Paul Stoffregen (http://www.pjrc.com)
-- 20MHz processor support by Garrett Mace (http://www.macetech.com)
-- ATmega1280/2560 support by Brett Hagman (http://www.roguerobotics.com/)

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
The latest version of this library can always be found at
http://arduiniana.org.
*/

#include <avr/interrupt.h>
#include <avr/pgmspace.h>
#include <avr/io.h>
#include <stdlib.h>
#include <stdbool.h>

//#include "WConstants.h"
//#include "pins_arduino.h"
#include "serial.h"
//
// Lookup table
//
typedef struct _DELAY_TABLE
{
  long baud;
  unsigned short rx_delay_centering;
  unsigned short rx_delay_intrabit;
  unsigned short rx_delay_stopbit;
  unsigned short tx_delay;
} DELAY_TABLE;

#if F_CPU == 16000000

static const DELAY_TABLE PROGMEM table[] = 
{
  //  baud    rxcenter   rxintra    rxstop    tx
  { 115200,   1,         17,        17,       12,    },
  { 57600,    10,        37,        37,       33,    },
  { 38400,    25,        57,        57,       54,    },
  { 31250,    31,        70,        70,       68,    },
  { 28800,    34,        77,        77,       74,    },
  { 19200,    54,        117,       117,      114,   },
  { 14400,    74,        156,       156,      153,   },
  { 9600,     114,       236,       236,      233,   },
  { 4800,     233,       474,       474,      471,   },
  { 2400,     471,       950,       950,      947,   },
  { 1200,     947,       1902,      1902,     1899,  },
  { 300,      3804,      7617,      7617,     7614,  },
};

const int XMIT_START_ADJUSTMENT = 5;

#elif F_CPU == 8000000

static const DELAY_TABLE table[] PROGMEM = 
{
  //  baud    rxcenter    rxintra    rxstop  tx
  { 115200,   1,          5,         5,      3,      },
  { 57600,    1,          15,        15,     13,     },
  { 38400,    2,          25,        26,     23,     },
  { 31250,    7,          32,        33,     29,     },
  { 28800,    11,         35,        35,     32,     },
  { 19200,    20,         55,        55,     52,     },
  { 14400,    30,         75,        75,     72,     },
  { 9600,     50,         114,       114,    112,    },
  { 4800,     110,        233,       233,    230,    },
  { 2400,     229,        472,       472,    469,    },
  { 1200,     467,        948,       948,    945,    },
  { 300,      1895,       3805,      3805,   3802,   },
};

const int XMIT_START_ADJUSTMENT = 4;

#error This version of NewSoftSerial supports only 16 and 8MHz processors

#endif

#define HIGH 1
#define LOW 0

// per object data
uint8_t _receivePin;
uint8_t _receiveBitMask;
volatile uint8_t *_receivePortRegister;
uint8_t _transmitBitMask;
volatile uint8_t *_transmitPortRegister;

uint16_t _rx_delay_centering;
uint16_t _rx_delay_intrabit;
uint16_t _rx_delay_stopbit;
uint16_t _tx_delay;

uint16_t _buffer_overflow=1;
uint16_t _inverse_logic=1;

// static data
static char _receive_buffer[_SS_MAX_RX_BUFF]; 
static volatile uint8_t _receive_buffer_tail;
static volatile uint8_t _receive_buffer_head;

// public only for easy access by interrupt handlers
static inline void ser_handle_interrupt(void);

//
// Private methods
//

/* static */ 
inline void ser_tunedDelay(uint16_t delay) { 
  uint8_t tmp=0;
  register uint16_t dly asm("r24") = delay;

  asm volatile("sbiw    %0, 0x01 \n\t"
    "ldi %1, 0xFF \n\t"
    "cpi %A0, 0xFF \n\t"
    "cpc %B0, %1 \n\t"
    "brne .-10 \n\t"
    : "+r" (dly), "+a" (tmp)
    : "0" (dly)
    );
}

bool _listening = false;

bool ser_listen()
{
  _buffer_overflow = false;
  uint8_t oldSREG = SREG;
  cli();
  _receive_buffer_head = _receive_buffer_tail = 0;
  SREG = oldSREG;

  _listening = true;
  
  return true;
}

//
// The receive routine called by the interrupt handler
//
void ser_recv()
{
  uint8_t d = 0;

  // If RX line is high, then we don't see any start bit
  // so interrupt is probably not for us
  if (_inverse_logic ? ser_rx_pin_read() : !ser_rx_pin_read())
  {
    // Wait approximately 1/2 of a bit width to "center" the sample
    ser_tunedDelay(_rx_delay_centering);

    // Read each of the 8 bits
    for (uint8_t i=0x1; i; i <<= 1)
    {
      ser_tunedDelay(_rx_delay_intrabit);
      uint8_t noti = ~i;
      if (ser_rx_pin_read())
        d |= i;
      else // else clause added to ensure function timing is ~balanced
        d &= noti;
    }

    // skip the stop bit
    ser_tunedDelay(_rx_delay_stopbit);

    if (_inverse_logic)
      d = ~d;

    // if buffer full, set the overflow flag and return
    if ((_receive_buffer_tail + 1) % _SS_MAX_RX_BUFF != _receive_buffer_head) 
    {
      // save new data in buffer: tail points to where byte goes
      _receive_buffer[_receive_buffer_tail] = d; // save new byte
      _receive_buffer_tail = (_receive_buffer_tail + 1) % _SS_MAX_RX_BUFF;
    } 
    else 
    {
      _buffer_overflow = true;
    }
  }
}

void ser_tx_pin_write(uint8_t pin_state)
{
  if (pin_state == LOW) {
    //*_transmitPortRegister &= ~_transmitBitMask;
    PORTB &= ~(1<<7);
  } else {
    PORTB |= (1<<7);
    //*_transmitPortRegister |= _transmitBitMask;
  }
}

uint8_t ser_rx_pin_read()
{
  return (PINE&(1<<6));
  //return *_receivePortRegister & _receiveBitMask;
}

//
// Interrupt handling
//

static inline void ser_handle_interrupt()
{
  ser_recv();
}

ISR(INT6_vect)
{
  ser_handle_interrupt();
}

//
// Constructor
//
void ser_init(volatile uint8_t* rx_port, uint8_t rx_pin, volatile uint8_t* tx_port, uint8_t tx_pin, bool inverse_logic)
{
  _rx_delay_centering = 0;
  _rx_delay_intrabit = 0;
  _rx_delay_stopbit = 0;
  _tx_delay = 0;
  _buffer_overflow = false;
  _inverse_logic = inverse_logic;
  ser_set_tx(rx_port, rx_pin);
  ser_set_rx(rx_port, rx_pin);
}

bool ser_is_listening() {
  return _listening;
}

bool ser_overflow() {
  bool ret = _buffer_overflow;
  _buffer_overflow = false;
  return ret;
}

#define output_low(port,pin) *port &= ~(1<<pin)
#define output_high(port,pin) *port |= (1<<pin)

void ser_set_tx(volatile uint8_t* port, uint8_t pin)
{
  output_high(port, pin);
  //digitalWrite(tx, HIGH);
  _transmitBitMask = (1<<pin);
  _transmitPortRegister = port;
}

void ser_set_rx(volatile uint8_t* port, uint8_t pin)
{
  //if (!_inverse_logic)
    //  digitalWrite(rx, HIGH);  // pullup for normal logic!
  //_receivePin = rx;
  _receiveBitMask = (1<<pin);
  _receivePortRegister = port;
}

//
// Public methods
//
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

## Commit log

2022-06-05 add SCAD & QMK folders
    [lorize-desktop.scad, lorize-keyfuncs.scad, lorize.scad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]
2022-06-05 update keyboard-fw
    [BoardDeviceMap.cfg, BootloaderDeviceMap.cfg]
2022-06-05 initial merge of PCB
    [2005280040.stp, 500SSPxS2M2xEA.stp, CPG135001D02 BROWN v5.step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]
